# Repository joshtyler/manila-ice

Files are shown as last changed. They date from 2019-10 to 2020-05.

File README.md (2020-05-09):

# manila iCE

manila iCE is a credit card sized Lattice iCE40 development board.

Quick links:
* [Schematic](https://github.com/joshtyler/manila-ice/releases/download/hardware_v1.0/manila_ice-schematic.pdf)
* [Gerbers](https://github.com/joshtyler/manila-ice/releases/download/hardware_v1.0/manila_ice-fab.zip)

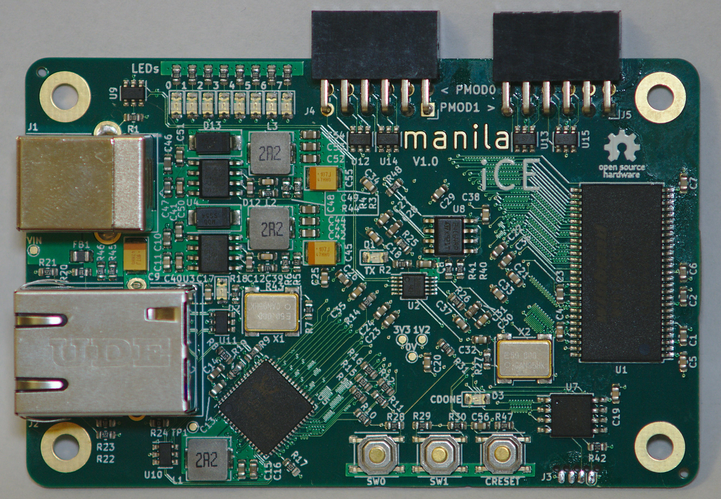
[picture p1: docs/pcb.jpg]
PCB


Features:
* Credit card sized (85x54mm)
* iCE40 HX4K FPGA (usable as an 8k device in yosys)
* Gigabit Ethernet
* 128Mbit SDRAM
* Two dual row PMODs
* 128Mbit QSPI flash
* USB UART (2Mbaud speed)
* 50MHz oscillator
* 64kbit I2C EEPROM
* 8 LEDs
* 2 push buttons
* 3A 3V3 and 1V2 power supplies

## Bootloader

The board has a bootloader which supports loading of FPGA bitstreams over UART. Four slots for bitstreams are supported. The first is reserved for the bootloader itself, and the other three can hold user images.

The FPGA is configured with the bootloader on powerup, and then automatically boots into the first bitstream after a timeout. Alternate bitstreams can be selected using the buttons, or by UART command.

## Example applications

The following applications are provided to demonstrate functionality of the PCB:
* UART loopback
* SDRAM controller
* Gigabit ethernet loopback

## Programming Application

To support uploading user applications, a Linux software utility is provided to update any of the bitstream slots.

To install the software checkout this repository, and run the following commands:
1. `cd sw/scripts`
1. `make`
1. `make install`

You will now have an executable called `manila` in your path.

To program the FPGA:
1. Plug in the board with USB
1. Press either of the switches to pause the boot process (optional if you're quick!)
1. `manila prog [path to bitstream]`

To discover the optional arguments run `manila prog` without any arguments.

## SPI Flash

The SPI flash memory is laid out as follows:

Flash Layout

The bootloader partition is protected to prevent accidental erasure.

## Bootloader Upgrades

In order to allow for firmware upgrades the protection is volatile. When the firmware is configured with the bootloader, before UART commands are accpeted it sends commands to the SPI flash to write protect the bootloader region, and then locks out that configuration until the SPI flash is power cycled.

TODO: document process for upgrading bootloader

## PCB Errata
* v1.0 - No known issues affecting functionality
	* LEDs in ethernet phy do not light due to symbol error
	* Silkscreen box around phtograph on back does not fully enclose image after fab
	* Caption for photograph on back is difficult to read

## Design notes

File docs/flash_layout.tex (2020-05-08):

\documentclass{standalone}

\usepackage{bytefield}

% Memory layout taken from https://www.martin-demling.de/2011/06/memory-maps-in-latex-using-the-bytefield-package/
\newcommand{\memsection}[4]{
	\bytefieldsetup{bitheight=#3\baselineskip}    % define the height of the memsection
	\bitbox[]{10}{
		\texttt{#1}     % print end address
		\\ \vspace{#3\baselineskip} \vspace{-2\baselineskip} \vspace{-#3pt} % do some spacing
		\texttt{#2} % print start address
	}
	\bitbox{16}{#4} % print box with caption
}

\begin{document}
\begin{bytefield}{24}
	\memsection{ffffff}{100000}{10}{Free}\\
	\begin{rightwordgroup}{Slot 3}
		\memsection{0fffff}{0e0fbc}{3}{Application specific data}\\
		\memsection{0e0fbb}{0c0000}{4}{Image}
	\end{rightwordgroup}\\
	\begin{rightwordgroup}{Slot 2}
		\memsection{0bffff}{0a0fbc}{3}{Application specific data}\\
		\memsection{0a0fbb}{080000}{4}{Image}
	\end{rightwordgroup}\\
	\begin{rightwordgroup}{Slot 1}
		\memsection{07ffff}{060fbc}{3}{Application specific data}\\
		\memsection{060fbb}{040000}{4}{Image}
	\end{rightwordgroup}\\
	\begin{rightwordgroup}{Slot 0 (Bootloader) \\ \textbf{Write protected}}
		\memsection{03ffff}{02105c}{3}{Reserved}\\
		\memsection{02105b}{0000a0}{4}{Bootloader image}\\
		\memsection{00009f}{000000}{3}{Multiboot header}
	\end{rightwordgroup}\\
\end{bytefield}
\end{document}

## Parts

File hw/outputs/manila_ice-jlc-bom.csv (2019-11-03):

Comment | Designator | Footprint | LCSC Part #
100n Unpolarized capacitor | C1,C2,C3,C4,C5,C6,C7,C8,C15,C13,C17,C27,C30,C21,C22,C24,C25,C20,C26,C19,C33,C32,C29,C23,C18,C34,C35,C36,C37,C56,C38,C41,C11,C51,C47 | C_0603_1608Metric | C14663
100u Polarized capacitor | C9,C45,C55 | CP_EIA-3528-21_Kemet-B | C16133
22u Unpolarized capacitor | C10,C43,C42,C44,C46,C53,C52,C54 | C_0603_1608Metric | C59461
10p Unpolarized capacitor | C12,C48 | C_0603_1608Metric | C1634
4u7 Unpolarized capacitor | C16,C14,C28,C31 | C_0603_1608Metric | C19666
1n Unpolarized capacitor | C39,C49 | C_0603_1608Metric | C1588
10n Unpolarized capacitor | C40,C50 | C_0603_1608Metric | C57112
LED Light emitting diode | D1,D2,D3,D4,D5,D6,D7,D8,D9,D10,D11 | D_0805_2012Metric_Castellated | C84256
SS54 Diode | D12,D13 | D_SMA | C22452
GZ2012D101TF Ferrite bead | FB1 | L_0805_2012Metric | C1015
2u2 Inductor | L1,L2,L3 | L_Sunlord_MWSA0518_5.4x5.2mm | C408345
1k Resistor | R1,R2,R31,R32,R33,R34,R35,R36,R37,R38,R39 | R_0603_1608Metric | C21190
7k5 Resistor | R3 | R_0603_1608Metric | C23234
1k2 Resistor | R5 | R_0603_1608Metric | C22765
2k4 Resistor | R6,R4,R19 | R_0603_1608Metric | C22940
91 Resistor | R8 | R_0603_1608Metric | C25199
510 Resistor | R20,R23,R18 | R_0603_1608Metric | C23193
4k7 Resistor | R21,R22,R17,R15,R13,R12,R11,R16,R10,R14 | R_0603_1608Metric | C23162
0R Resistor | R24 | R_0603_1608Metric | C21189
100 Resistor | R25,R26,R47 | R_0603_1608Metric | C22775
10k Resistor | R41,R40,R48,R7,R9,R30,R29,R28,R27,R42 | R_0603_1608Metric | C25804
43k Resistor | R43,R44 | R_0603_1608Metric | C23172
360k Resistor | R45 | R_0603_1608Metric | C23146
180k Resistor | R46 | R_0603_1608Metric | C22827
SW_SPST Single Pole Single Throw (SPST) switch | SW3,SW2,SW1 | SW_Push_1P1T_NO_5.1x5.1mm | C318888
W9812G6KH-6 128Mb Synchronous DRAM, 2 Mb x 16 b x 4 Banks, 166 MHz, TSOP-II-54 | U1 | TSOP-II-54_22.2x10.16mm_P0.8mm | C62379
CH340E USB serial converter, UART, MSOP-10 | U2 | MSOP-10_3x3mm_P0.5mm | C99652
TPS54331D 3A, Step Down DC-DC Converter with Eco-mode, 3.5-28V Input Voltage, SO-8 | U3,U4 | SOIC-8_3.9x4.9mm_P1.27mm | C9865
RTL8211EG-VB-CG 10/100/1000Mbps Ethernet Transceiver with RGMII/GMII/MII/RMII Interface | U5 | QFN-64-1EP_9x9mm_P0.5mm_EP3.8x3.8mm_ThermalVias | C69264
W25Q128JVS 128Mb Serial Flash Memory, Standard/Dual/Quad SPI, SOIC-8 | U7 | SOIC-8_5.23x5.23mm_P1.27mm | C97521
M24C01-RMN 1Kb (128x8) I2C Serial EEPROM, 1.8-5.5V, SOIC-8 | U8 | SOIC-8_3.9x4.9mm_P1.27mm | C79988
SRV05-4 ESD Protection Diodes with Low Clamping Voltage, SOT-23-6 | U9,U10,U11,U12,U14,U13,U15 | SOT-23-6 | C85364
SG-7050CAN CMOS Clock Oscillator 1 to 75 MHz | X1,X2 | Oscillator_SMD_SeikoEpson_SG8002CA-4Pin_7.0x5.0mm | C70528

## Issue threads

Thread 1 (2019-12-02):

Very nice board.

janrinze, 2019-12-02:
I like this board.
SDRAM + 2x PMOD is really nice.
If you will be having any spares then I am willing to buy one from you.

Great work!
Jan Rinze.

joshtyler, 2019-12-03:
Hi Jan,

Thank you, I'm glad you like it. I'm impressed that you found the board given that I haven't got around to uploading any documentation yet!

I've had a few boards manufactured and am now testing them.
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

I wanted to try out whether it was possible to get any reasonable gigabit ethernet performance with an iCE40 FPGA, so I put together this credit card sized dev board. It has a GE Phy, SDRAM, 2 PMODs, a reasonable size QSPI flash, and a USB UART. There are also a couple of switches, 8 debug LEDs, and an EEPROM to store things like serial numbers and MAC addresses.

So far I've tested that the power rails come up, that FPGA can configure itself and blink the LEDs, the USB UART, and that the PHY is able to negotiate to 1000BASE-T.

I'm just writing a small bootloader to take in a configuration image over the UART interface and save it into flash, then it should be usable as a standalone unit.

Once I've gotten this done, and tested the other interfaces, I'll let you know, as I should have a few spare boards. Progress might be a bit slow though, as I'm just working on this in a bit of my spare time!

janrinze, 2020-02-19:
Hi, it's been a while.
How is it going with the board?

joshtyler, 2020-02-29:
Hi Jan,

I've got the serial bootloader working, so I can now upload code to the board without a separate programming cable - I've just got to test the various peripherals and interfaces now.

joshtyler, 2020-10-25:
Hi Jan,

Sorry for not getting back to you, this Issue completely slipped my mind! I do have a few spare boards. Happy to sell one to you.

Give me an email at josh.tyler@btinternet.com if you are still interested and we can discuss :smile:

Josh

Closed 2020-10-25.

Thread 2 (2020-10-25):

BOM cost?

taktoa, 2020-10-25:
I'm designing a similar board (HX4K + gigabit ethernet PHY) and I'm curious what your BOM cost ended up being? What about total cost per board from JLC (including board, stencil, assembly, etc.)? If my design ends up being more expensive, I'll know I did something wrong :-)

joshtyler, 2020-10-25:
Hi @taktoa,

You can play around with pricing yourself if you like. You just need the following files:
https://github.com/joshtyler/manila-ice/blob/master/hw/outputs/fab.zip
https://github.com/joshtyler/manila-ice/blob/master/hw/outputs/manila_ice-jlc-bom.csv
https://github.com/joshtyler/manila-ice/blob/master/hw/outputs/manila_ice-jlc-cpl-top.csv

Just drag fab.zip onto the JLC quote form, select SMT assembly, then upload the CSV files when prompted. I've just done a quick check and the assembled board currently costs $100.12 in quantity 5 (without shipping, but with optional ENIG finish), I ordered slightly more PCBs and so paid a slightly lower unit cost.

JLC assemble everything on this board except for the FPGA (which is on the back of the PCB), and the connectors. I think I paid about $5 per FPGA from RS (a UK based distributor). The other connectors were from LCSC. The RJ45 I think was about $2 (it is a bit more expensive than others on the site because it has gigabit magnetics integrated). The PMOD connectors and USB connectors I think were tens of cents each.

You don't need to pay for a stencil explicitly (JLC bake it into the assembly cost) but if you want one shipped to you, then it costs $7.

Btw, if you're thinking of doing gigabit networking on the iCE40 FPGAs, bear in mind that the fabric is fairly slow, getting the ethernet interface working at 125 MHz can be a challenge. I can get a loopback test to meet timing at 125MHz no problem, but as I add more to the design, it becomes harder to meet timing. For example with a picorv32 CPU in there, the ethernet doesn't quite meet timing anymore (even though the ethernet clock domain just has a FIFO, and some discrete logic to drive the MII interface). I'm currently looking at implementing TCP in the FPGA logic, and I'm fairly confident that I will be able to get this to meet timing :smile:

taktoa, 2020-10-25:
Thanks! Gigabit is fortunately not important for my application, but I figured I'd rather have it and not use it than not have it and want it. My application is actually a microphone array for playing around with ultrasound sonar in air (e.g.: to make a depth camera), and the total data rate there is 72 Mb/s, but if I want to get into higher frequency ultrasound the gigabit would come in handy. My board will also have a microcontroller (leaning towards a RISC-V core, funnily enough) so the FPGA is really just there to route data and do serial-to-parallel / parallel-to-serial conversion; setting up protocols will be done by the microcontroller.

Closed 2020-10-25.

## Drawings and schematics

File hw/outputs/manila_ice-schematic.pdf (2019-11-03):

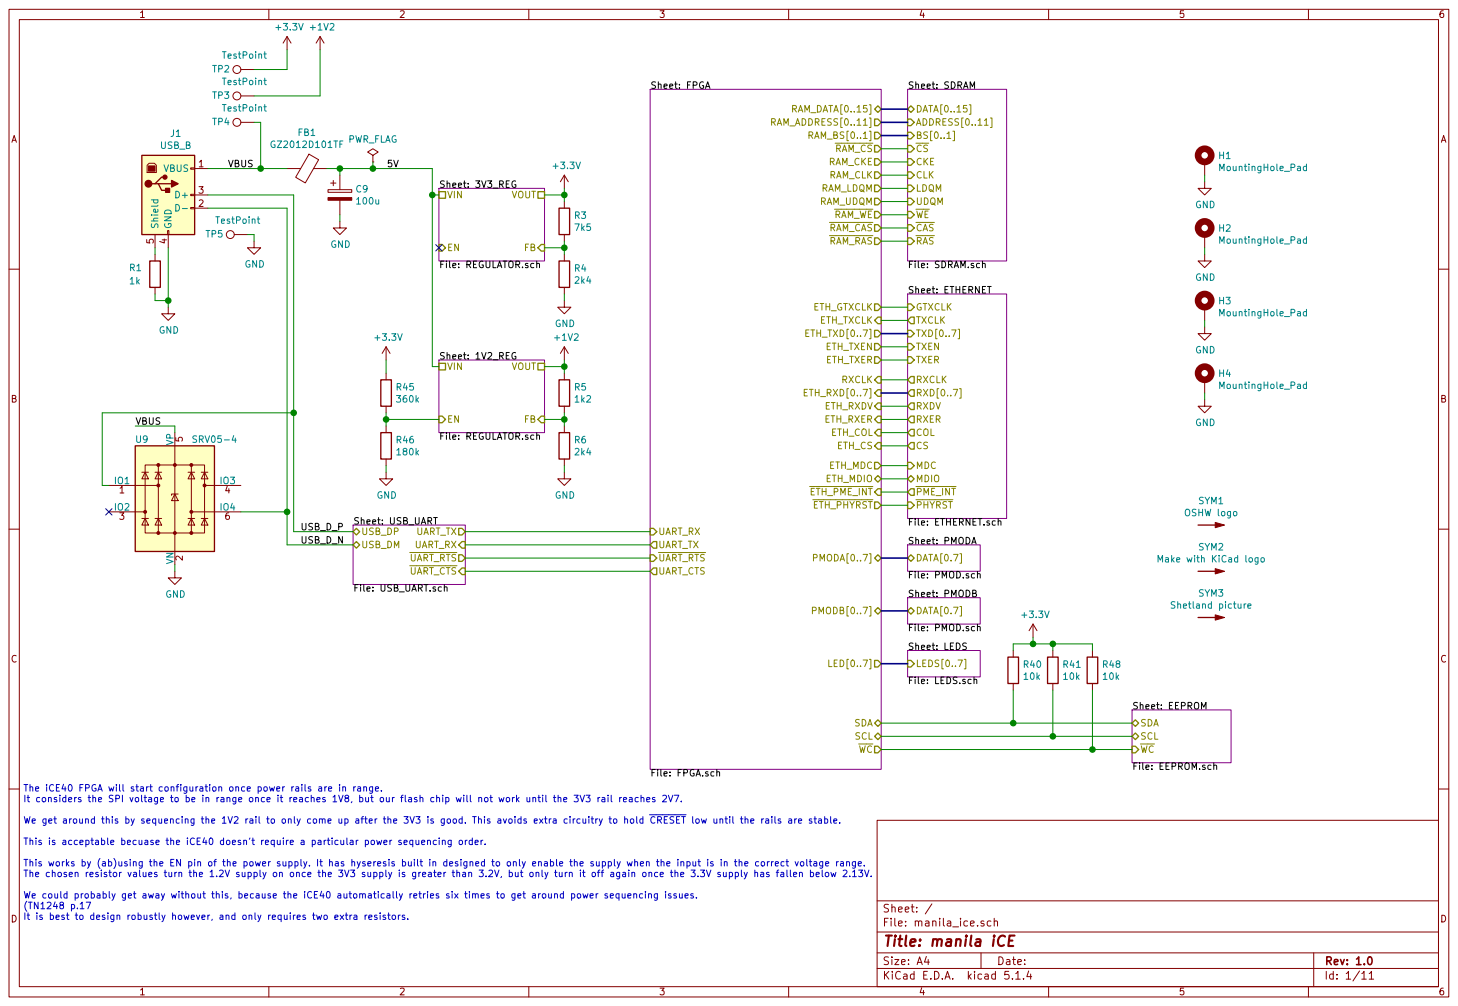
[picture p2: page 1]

DATA[0..15]
File: SDRAM.sch ADDRESS[0..11]
BS[0..1] CSCKE CLK

LDQM
UDQM WE CAS RAS
File: ETHERNET.sch GTXCLK
TXCLK
TXD[0..7] TXEN

SYM1 OSHW logo SYM2 Make with KiCad logo SYM3 Shetland picture GND

TXER
RXCLK RXD[0..7] RXDV RXER

COL CSMDC MDIO
LEDS[0..7] Sheet: PMODA
File: PMOD.sch DATA[0.7]

File: PMOD.sch DATA[0.7] GND

File: manila_ice.sch Sheet: / Sheet: USB_UART
File: USB_UART.sch USB_DP USB_DM

Sheet: EEPROM
File: EEPROM.sch SDA
SCL WC

The iCE40 FPGA will start configuration once power rails are in range.
It considers the SPI voltage to be in range once it reaches 1V8, but our flash chip will not work until the 3V3 rail reaches 2V7.

We get around this by sequencing the 1V2 rail to only come up after the 3V3 is good. This avoids extra circuitry to hold CRESET low until the rails are stable.

This is acceptable becuase the iCE40 doesn't require a particular power sequencing order.

This works by (ab)using the EN pin of the power supply. It has hyseresis built in designed to only enable the supply when the input is in the correct voltage range.
The chosen resistor values turn the 1.2V supply on once the 3V3 supply is greater than 3.2V, but only turn it off again once the 3.3V supply has fallen below 2.13V.

We could probably get away without this, because the iCE40 automatically retries six times to get around power sequencing issues.
It is best to design robustly however, and only requires two extra resistors.

Id: 1/11 Title: manila iCE

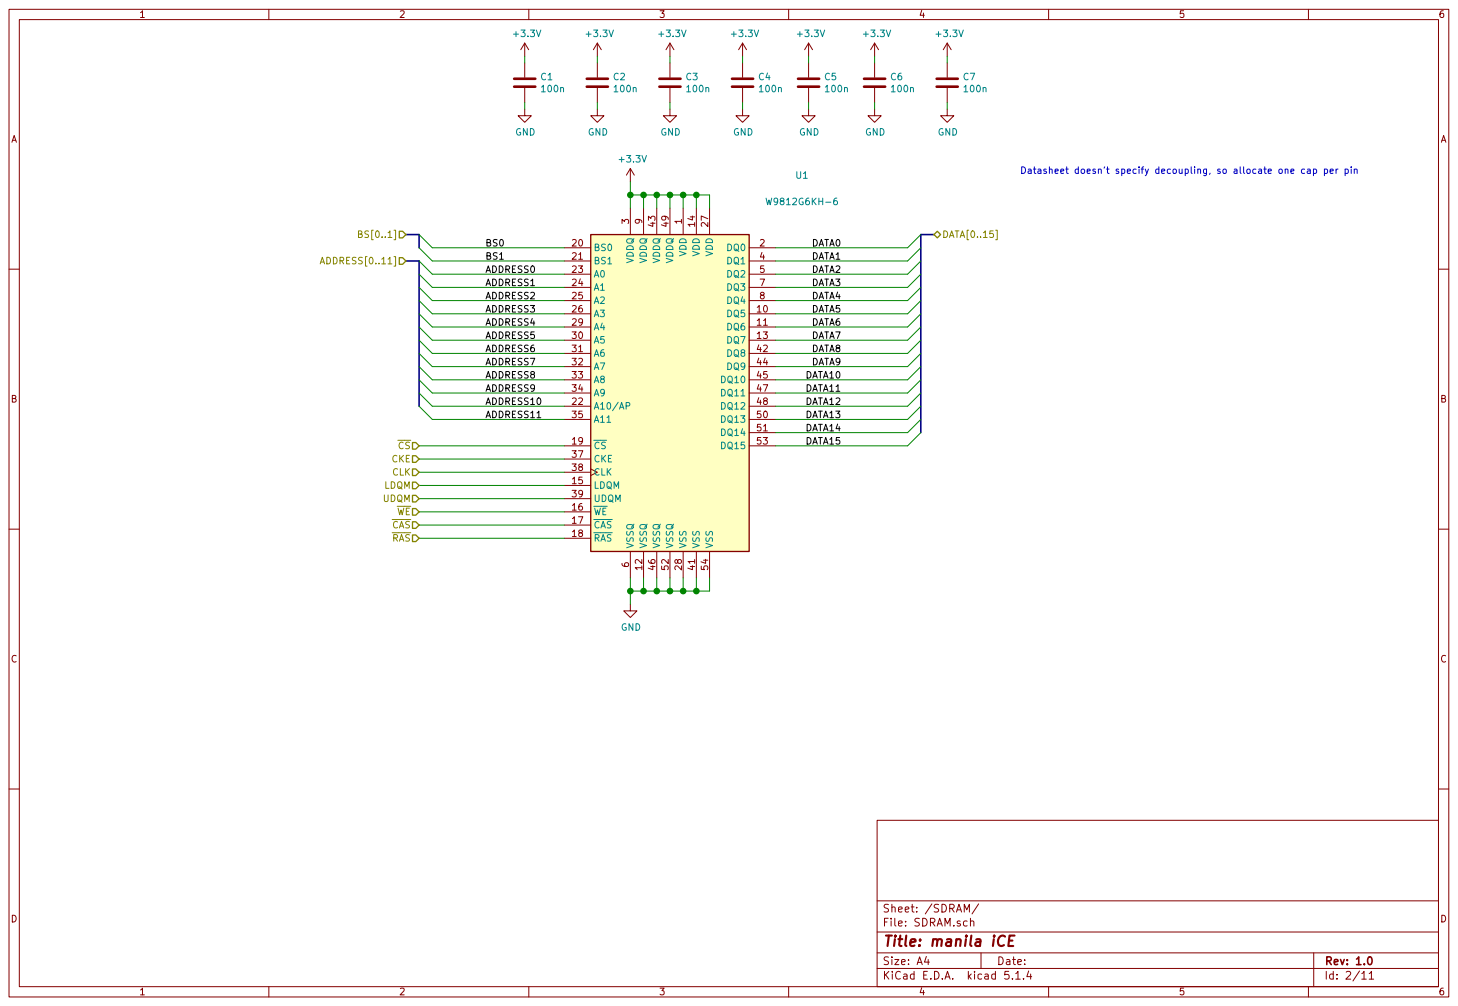
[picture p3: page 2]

100n ADDRESS[0..11]RAS CAS WE UDQM

3 A5 30 A6 31 A7 32 A8 33 A9 34 A11 35 CKE 37 CLK 38 UDQM 39 DQ1 4 VSS 41 DQ8 42 VDDQ 43 DQ9 44 DQ10 45 VSSQ 46 DQ11 47 DQ12 48 VDDQ 49 DQ2 5 DQ13 50 DQ14 51 VSSQ 52 DQ15 53 VSS 54 VSSQ

File: SDRAM.sch Sheet: /SDRAM/
Id: 2/11 Title: manila iCE

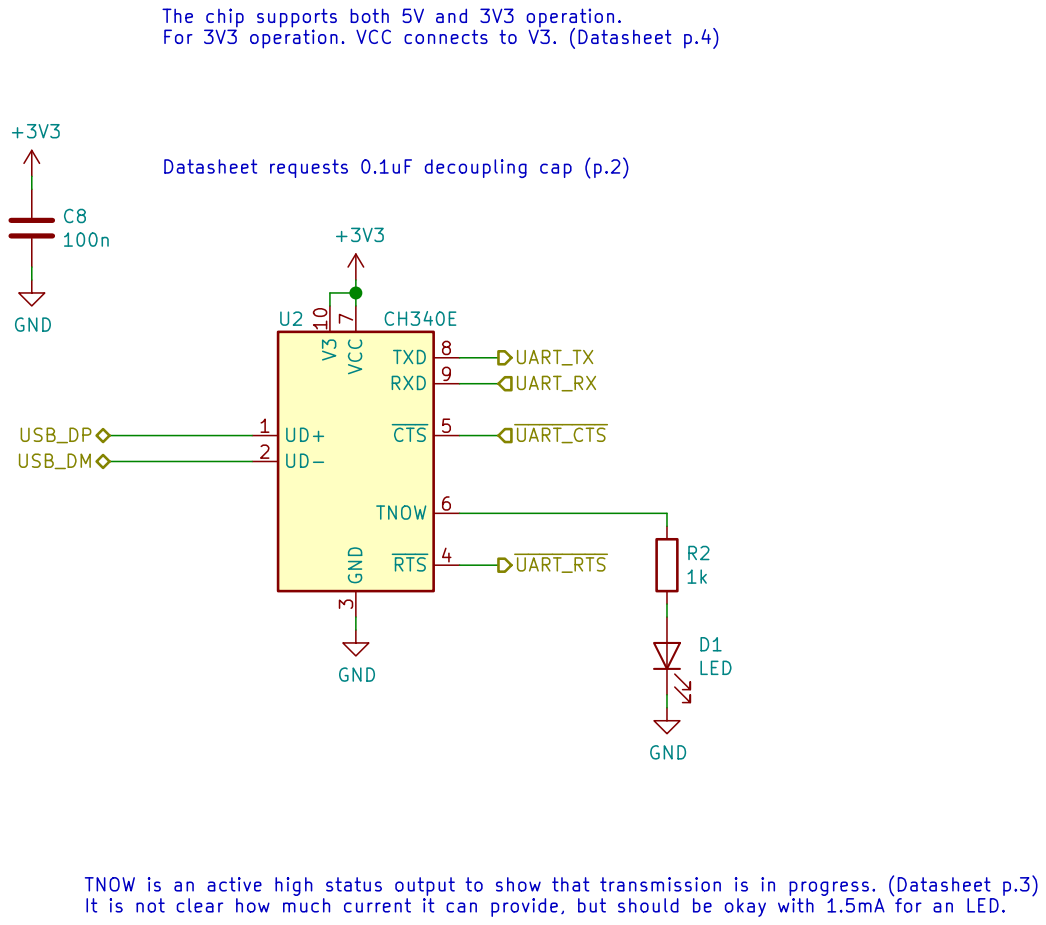
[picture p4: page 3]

The chip supports both 5V and 3V3 operation.
For 3V3 operation. VCC connects to V3. (Datasheet p.4)
100n +3V3 GND

3 RTS 4 CTS 5 TNOW 6 VCC

TNOW is an active high status output to show that transmission is in progress. (Datasheet p.3)
It is not clear how much current it can provide, but should be okay with 1.5mA for an LED.

File: USB_UART.sch
Id: 3/11 Title: manila iCE

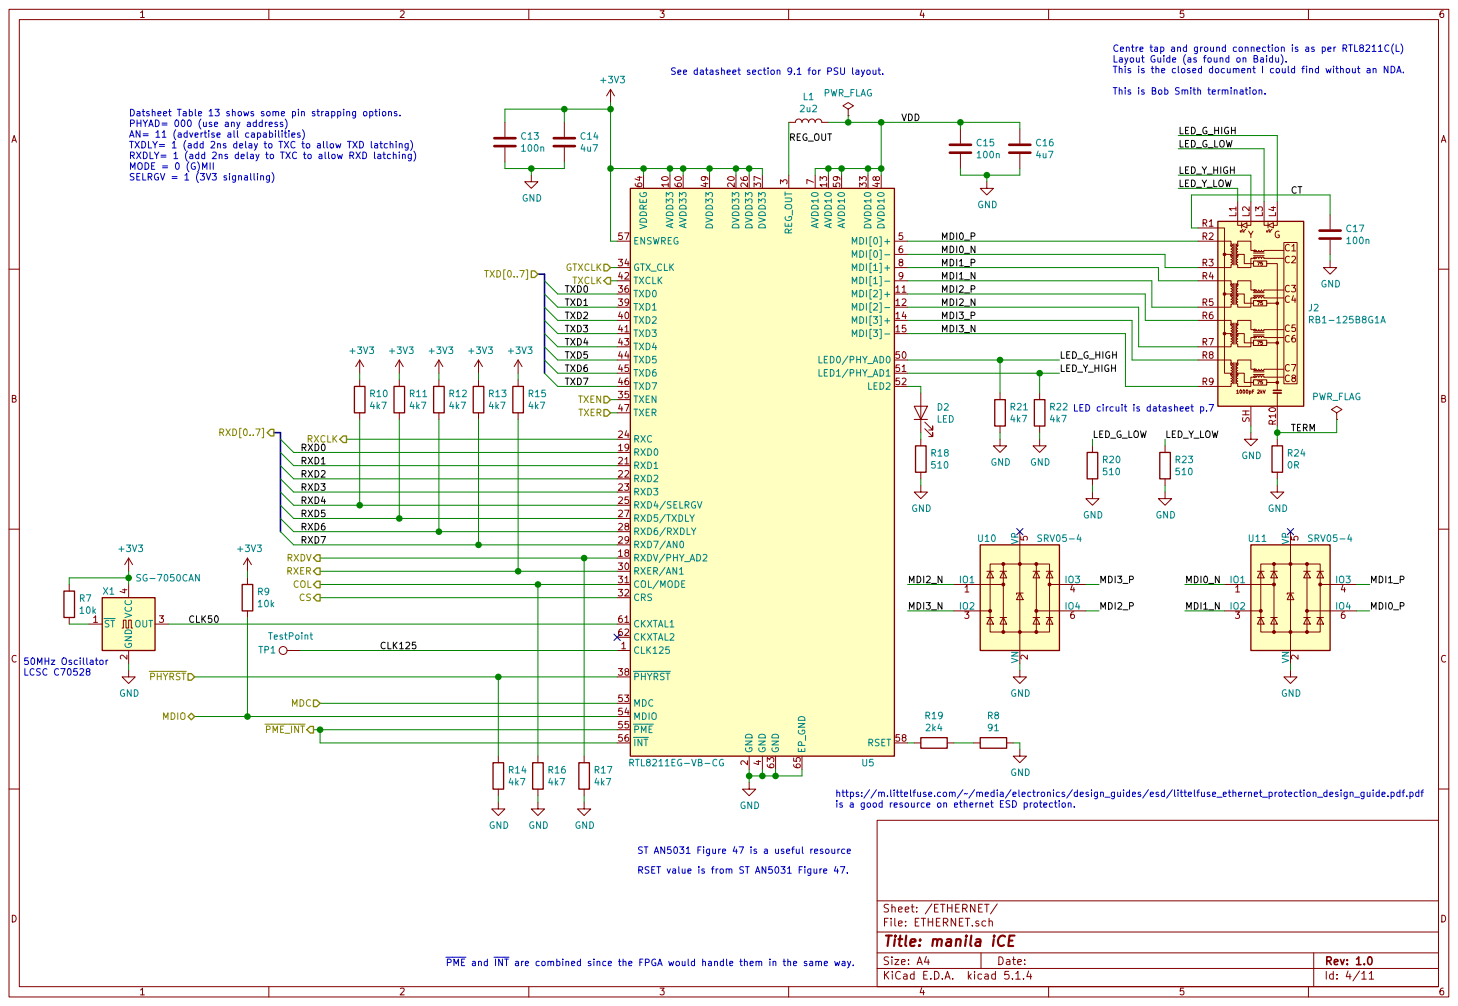
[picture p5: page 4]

Centre tap and ground connection is as per RTL8211C(L)
Layout Guide (as found on Baidu). This is the closed document I could find without an NDA. This is Bob Smith termination.

See datasheet section 9.1 for PSU layout.

Datsheet Table 13 shows some pin strapping options.
PHYAD= 000 (use any address)
AN= 11 (advertise all capabilities)
TXDLY= 1 (add 2ns delay to TXC to allow TXD latching)
RXDLY= 1 (add 2ns delay to TXC to allow RXD latching)
MODE = 0 (G)MII
SELRGV = 1 (3V3 signalling)

7 MDI[1]+ 8 MDI[1]- 9 RTL8211EG-VB-CG U5 +3V3 GND GND GND

2 DVDD33 20 RXD1 21 RXD2 22 RXD3 23 RXC 24 RXD4/SELRGV 25 DVDD33 26 RXD5/TXDLY 27 RXD6/RXDLY 28 RXD7/AN0 29 REG_OUT

3 RXER/AN1 30 COL/MODE 31 CRS 32 DVDD10 33 GTX_CLK 34 TXEN 35 TXD0 36 DVDD33 37 PHYRST 38 TXD1 39 GND

LED circuit is datasheet p.7

COL CS MDC MDIO

https://m.littelfuse.com//media/electronics/design_guides/esd/littelfuse_ethernet_protection_design_guide.pdf.pdf
is a good resource on ethernet ESD protection.

ST AN5031 Figure 47 is a useful resource
RSET value is from ST AN5031 Figure 47.

File: ETHERNET.sch Sheet: /ETHERNET/
Id: 4/11 Title: manila iCE

PME and INT are combined since the FPGA would handle them in the same way.

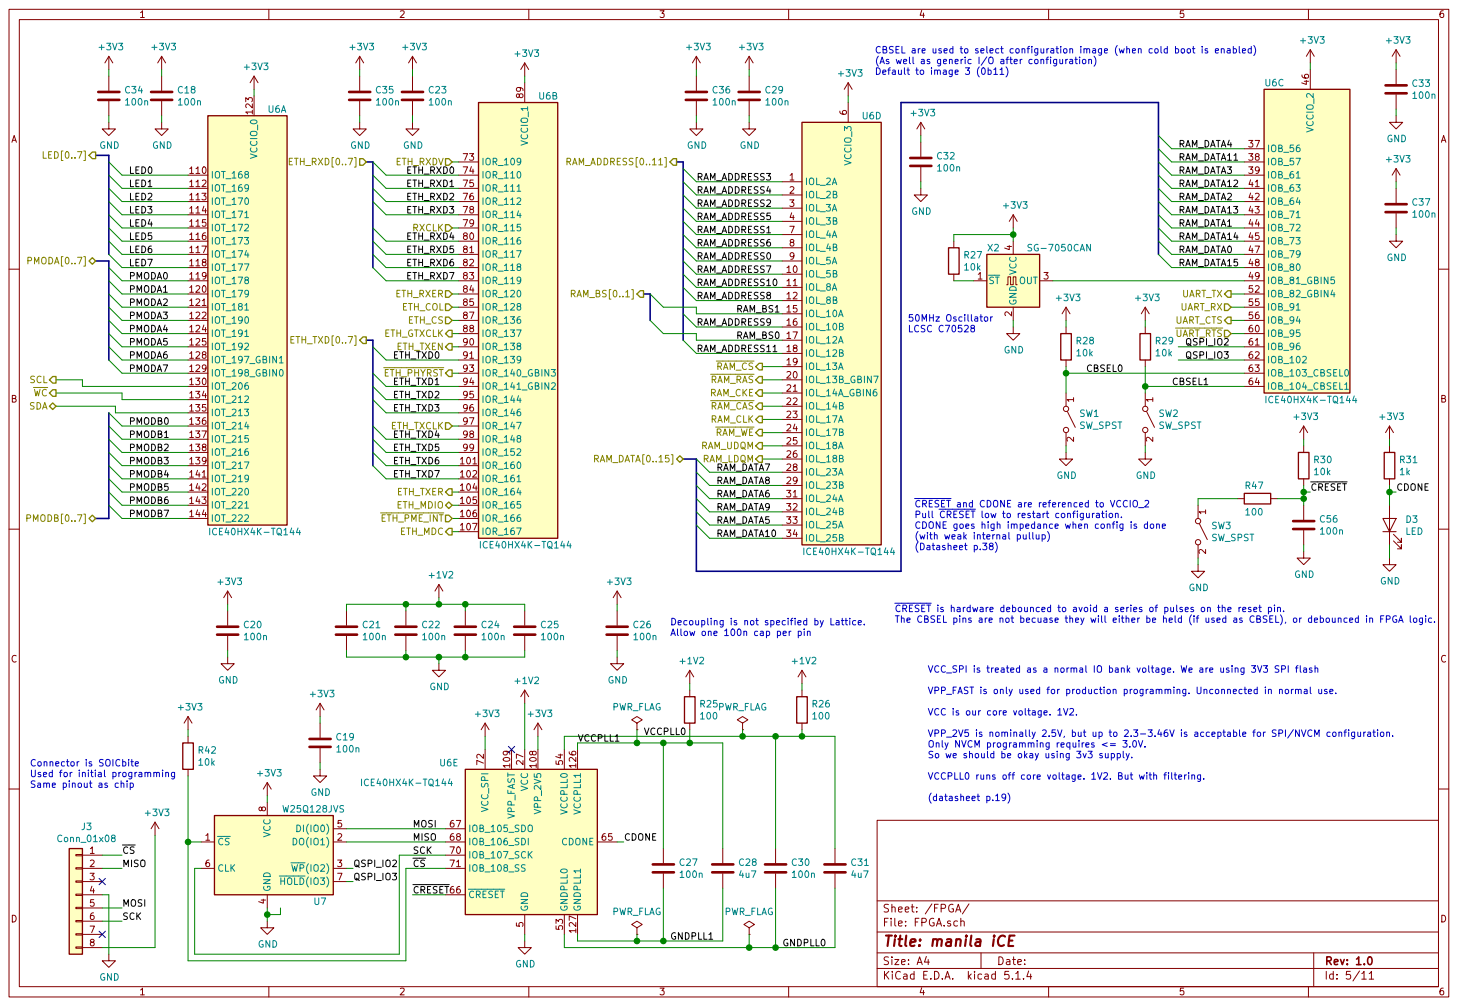
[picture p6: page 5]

CBSEL are used to select configuration image (when cold boot is enabled)
(As well as generic I/O after configuration)
Default to image 3 (0b11) CRESET and CDONE are referenced to VCCIO_2 Pull CRESET low to restart configuration.

CDONE goes high impedance when config is done
(with weak internal pullup)
(Datasheet p.38)

CRESET is hardware debounced to avoid a series of pulses on the reset pin.
The CBSEL pins are not becuase they will either be held (if used as CBSEL), or debounced in FPGA logic.

Decoupling is not specified by Lattice.
Allow one 100n cap per pin

VCC_SPI is treated as a normal IO bank voltage. We are using 3V3 SPI flash

VPP_FAST is only used for production programming. Unconnected in normal use.

VCC is our core voltage. 1V2.

VPP_2V5 is nominally 2.5V, but up to 2.3-3.46V is acceptable for SPI/NVCM configuration.
Only NVCM programming requires <= 3.0V.
So we should be okay using 3v3 supply.

Same pinout as chip

VCCPLL0 runs off core voltage. 1V2. But with filtering.

4 DI(IO0) 5 CLK 6 HOLD(IO3) 7 VCC
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

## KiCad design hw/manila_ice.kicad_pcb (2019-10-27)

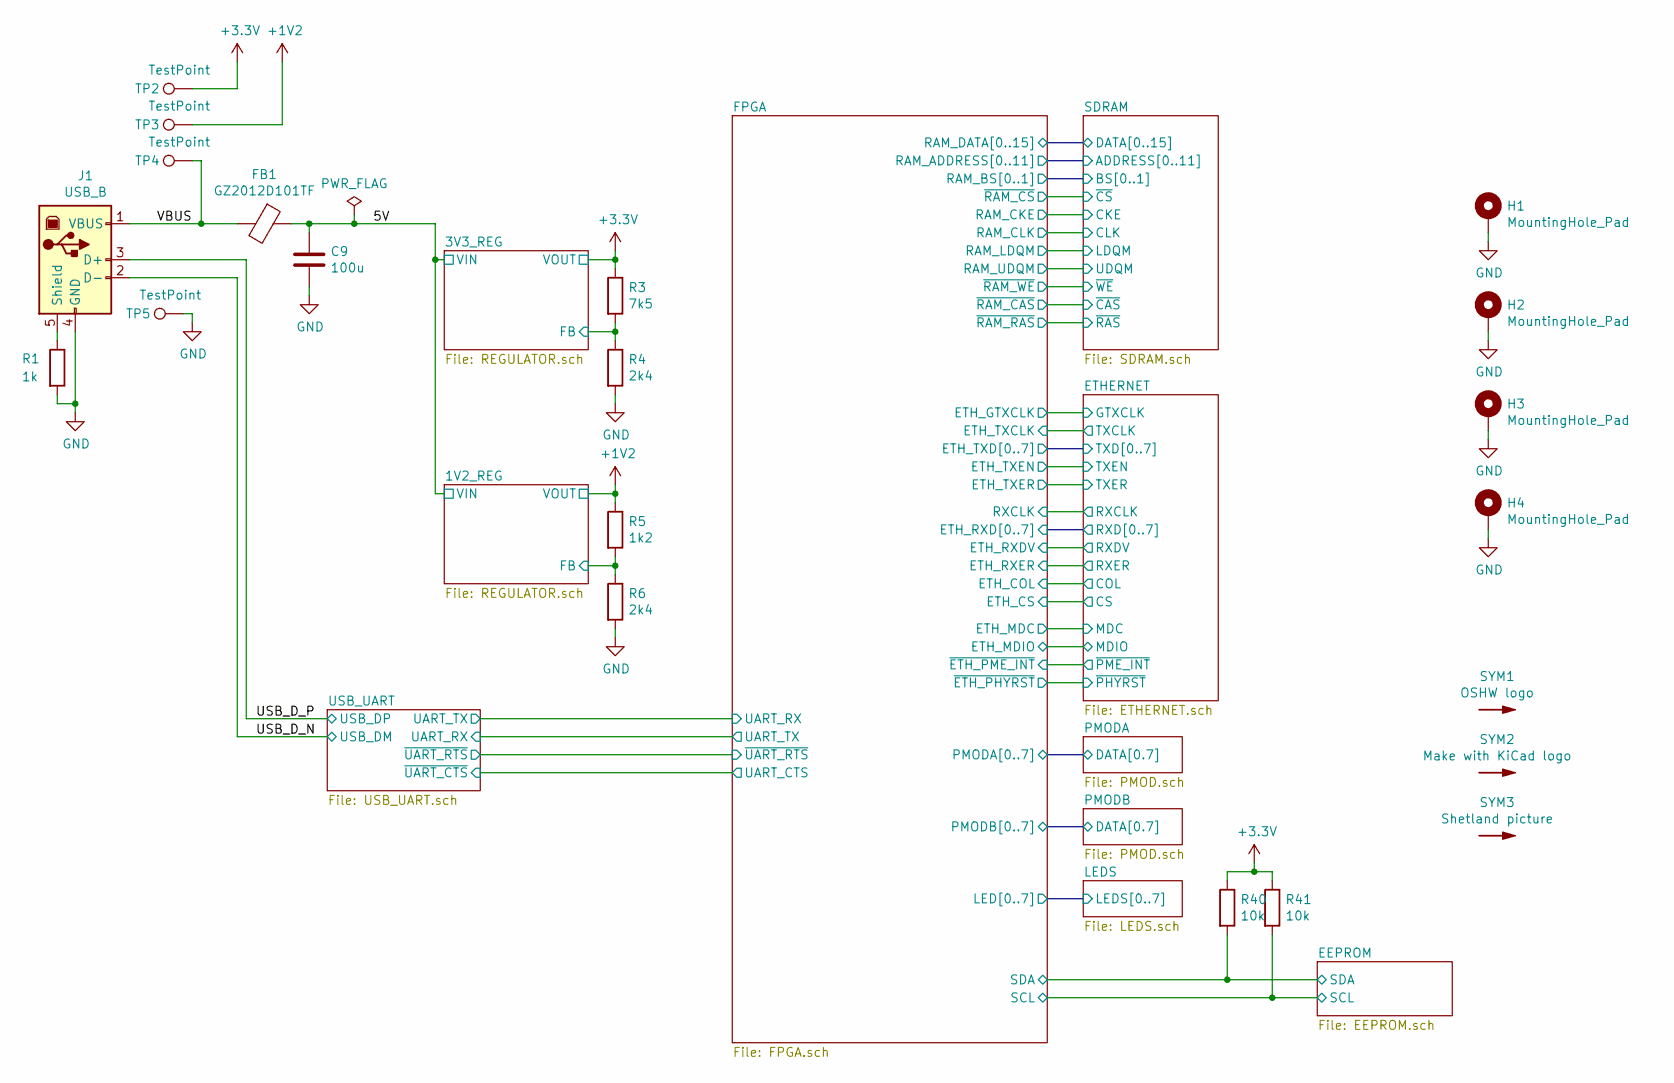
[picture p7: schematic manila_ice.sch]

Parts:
C9: 100u; CP_EIA-3528-21_Kemet-B; LCSC Part C16133
FB1: GZ2012D101TF; L_0805_2012Metric; LCSC Part C1015
H1, H2, H3, H4: MountingHole_Pad; MountingHole_3.2mm_M3_Pad; JLCPCB BOM 0
J1: USB_B; USB_B_OST_USB-B1HSxx_Horizontal; JLCPCB BOM 0
R1: 1k; R_0603_1608Metric; LCSC Part C21190
R3: 7k5; R_0603_1608Metric; LCSC Part C22452
R4, R6: 2k4; R_0603_1608Metric; LCSC Part C22940
R5: 1k2; R_0603_1608Metric; LCSC Part C22765
R40, R41: 10k; R_0603_1608Metric; LCSC Part C25804
SYM1: OSHW logo; OSHW-Logo_5.7x6mm_SilkScreen; JLCPCB BOM 0
SYM2: Make with KiCad logo; KiCad-Logo2_5mm_SilkScreen; JLCPCB BOM 0
SYM3: Shetland picture; Shetland_combined; JLCPCB BOM 0
TP2, TP3, TP4, TP5: TestPoint; TestPoint_Pad_D1.0mm; JLCPCB BOM 0

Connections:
+1V2: R5.1, TP3.1; also elsewhere on the board
/1V2_REG/FB: R5.2, R6.1; also elsewhere on the board
/3V3_REG/FB: R3.2, R4.1; also elsewhere on the board
/5V: C9.1, FB1.1; also elsewhere on the board
/EEPROM/SCL: R41.2; also elsewhere on the board
/EEPROM/SDA: R40.2; also elsewhere on the board
/USB_D_N: J1.2 (D-); also elsewhere on the board
/USB_D_P: J1.3 (D+); also elsewhere on the board
/VBUS: FB1.2, J1.1 (VBUS), TP4.1
GND: C9.2, H1.1, H2.1, H3.1, H4.1, J1.4 (GND), R1.2, R4.2, R6.2, TP5.1; also elsewhere on the board
unnamed: J1.5 (Shield), R1.1

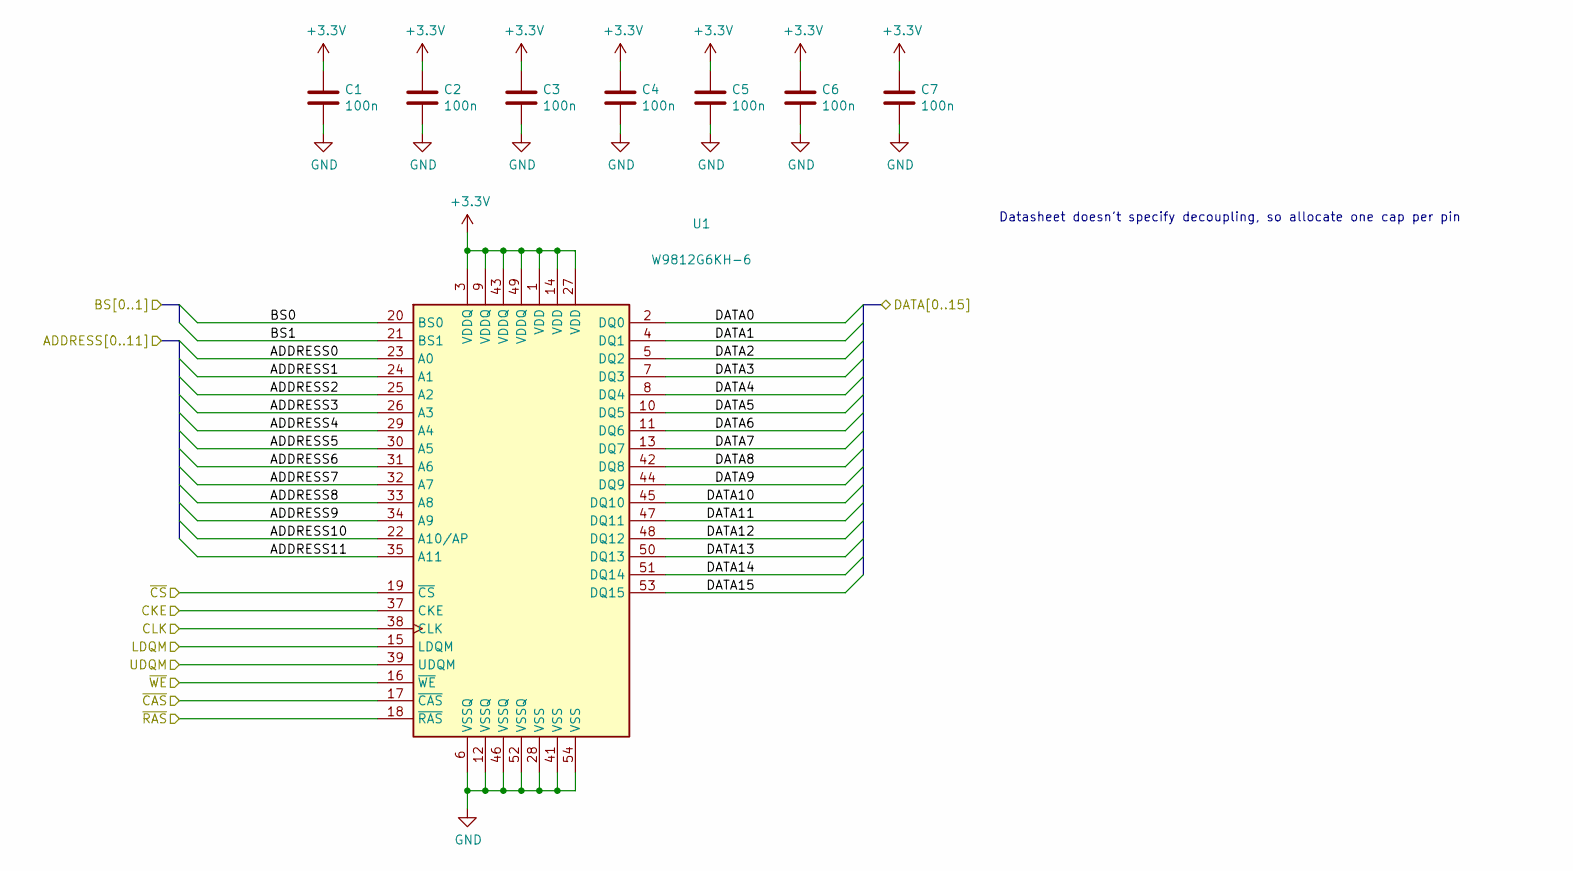
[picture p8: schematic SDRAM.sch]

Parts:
C1, C2, C3, C4, C5, C6, C7: 100n; C_0603_1608Metric; LCSC Part C14663
U1: W9812G6KH-6; TSOP-II-54_22.2x10.16mm_P0.8mm; LCSC Part C62379

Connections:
/FPGA/RAM_UDQM: U1.39 (UDQM); also elsewhere on the board
/FPGA/~RAM_RAS: U1.18 (~RAS); also elsewhere on the board
/FPGA/~RAM_WE: U1.16 (~WE); also elsewhere on the board
/SDRAM/ADDRESS0: U1.23 (A0); also elsewhere on the board
/SDRAM/ADDRESS1: U1.24 (A1); also elsewhere on the board
/SDRAM/ADDRESS2: U1.25 (A2); also elsewhere on the board
/SDRAM/ADDRESS3: U1.26 (A3); also elsewhere on the board
/SDRAM/ADDRESS4: U1.29 (A4); also elsewhere on the board
/SDRAM/ADDRESS5: U1.30 (A5); also elsewhere on the board
/SDRAM/ADDRESS6: U1.31 (A6); also elsewhere on the board
/SDRAM/ADDRESS7: U1.32 (A7); also elsewhere on the board
/SDRAM/ADDRESS8: U1.33 (A8); also elsewhere on the board
/SDRAM/ADDRESS9: U1.34 (A9); also elsewhere on the board
/SDRAM/ADDRESS10: U1.22 (A10/AP); also elsewhere on the board
/SDRAM/ADDRESS11: U1.35 (A11); also elsewhere on the board
/SDRAM/BS0: U1.20 (BS0); also elsewhere on the board
/SDRAM/BS1: U1.21 (BS1); also elsewhere on the board
/SDRAM/CKE: U1.37 (CKE); also elsewhere on the board
/SDRAM/CLK: U1.38 (CLK); also elsewhere on the board
/SDRAM/DATA0: U1.2 (DQ0); also elsewhere on the board
/SDRAM/DATA1: U1.4 (DQ1); also elsewhere on the board
/SDRAM/DATA2: U1.5 (DQ2); also elsewhere on the board
/SDRAM/DATA3: U1.7 (DQ3); also elsewhere on the board
/SDRAM/DATA4: U1.8 (DQ4); also elsewhere on the board
/SDRAM/DATA5: U1.10 (DQ5); also elsewhere on the board
/SDRAM/DATA6: U1.11 (DQ6); also elsewhere on the board
/SDRAM/DATA7: U1.13 (DQ7); also elsewhere on the board
/SDRAM/DATA8: U1.42 (DQ8); also elsewhere on the board
/SDRAM/DATA9: U1.44 (DQ9); also elsewhere on the board
/SDRAM/DATA10: U1.45 (DQ10); also elsewhere on the board
/SDRAM/DATA11: U1.47 (DQ11); also elsewhere on the board
/SDRAM/DATA12: U1.48 (DQ12); also elsewhere on the board
/SDRAM/DATA13: U1.50 (DQ13); also elsewhere on the board
/SDRAM/DATA14: U1.51 (DQ14); also elsewhere on the board
/SDRAM/DATA15: U1.53 (DQ15); also elsewhere on the board
/SDRAM/LDQM: U1.15 (LDQM); also elsewhere on the board
/SDRAM/~CAS: U1.17 (~CAS); also elsewhere on the board
/SDRAM/~CS: U1.19 (~CS); also elsewhere on the board
GND: C1.2, C2.2, C3.2, C4.2, C5.2, C6.2, C7.2, U1.6 (VSSQ), U1.12 (VSSQ), U1.28 (VSS), U1.41 (VSS), U1.46 (VSSQ), U1.52 (VSSQ), U1.54 (VSS); also elsewhere on the board

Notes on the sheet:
Datasheet doesn't specify decoupling, so allocate one cap per pin

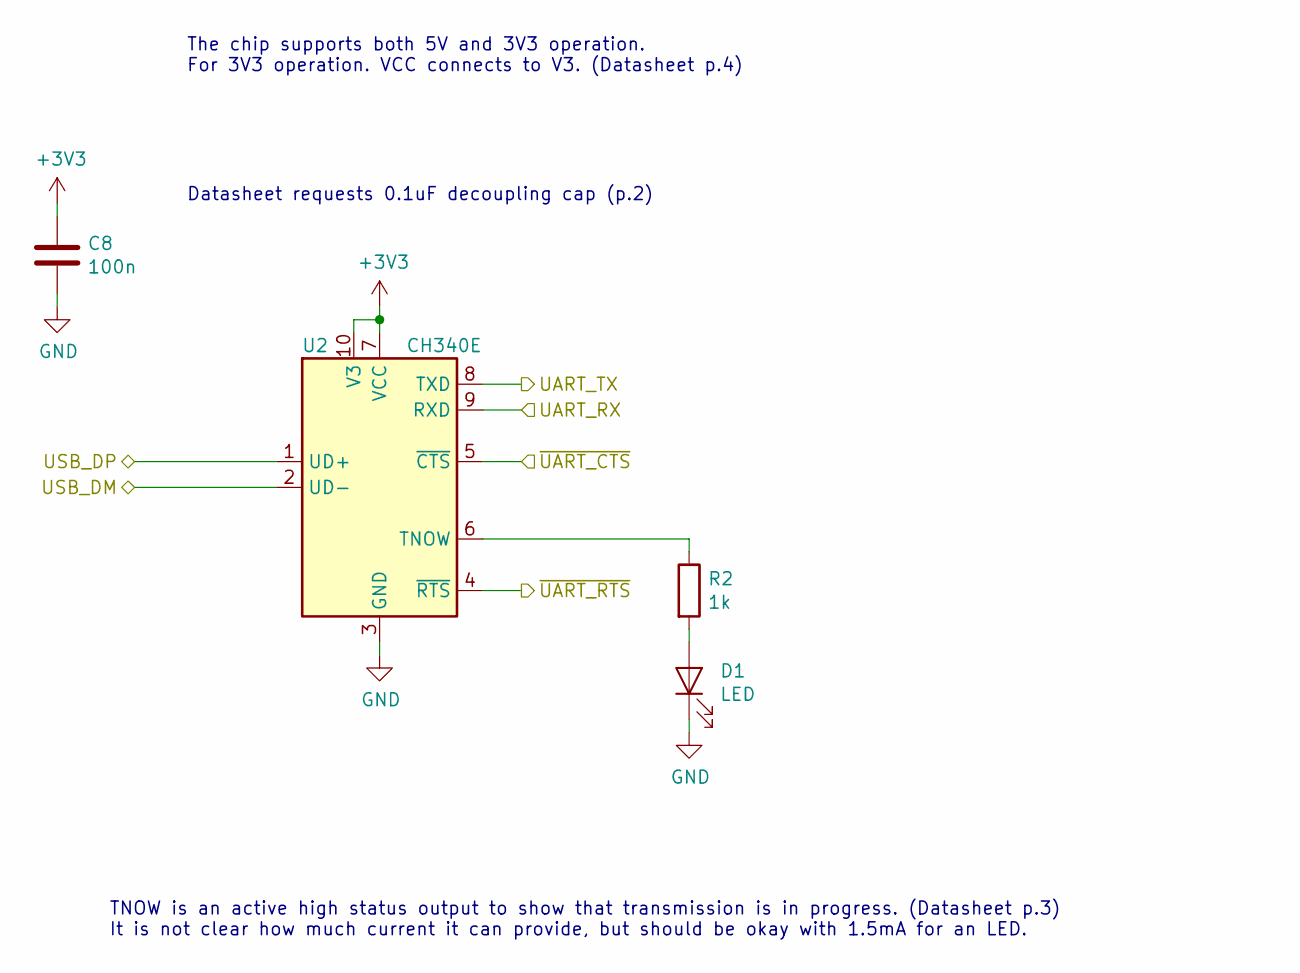
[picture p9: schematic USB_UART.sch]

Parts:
C8: 100n; C_0603_1608Metric; LCSC Part C14663
D1: LED; D_0805_2012Metric_Castellated; LCSC Part C84256
R2: 1k; R_0603_1608Metric; LCSC Part C21190
U2: CH340E; MSOP-10_3x3mm_P0.5mm; JLCPCB Rotation -90

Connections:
/FPGA/UART_CTS: U2.5 (~CTS); also elsewhere on the board
/FPGA/UART_RX: U2.8 (TXD); also elsewhere on the board
/FPGA/~UART_RTS: U2.4 (~RTS); also elsewhere on the board
/USB_D_N: U2.2 (UD-); also elsewhere on the board
/USB_D_P: U2.1 (UD+); also elsewhere on the board
/USB_UART/UART_RX: U2.9 (RXD); also elsewhere on the board
GND: C8.2, D1.1 (K), U2.3 (GND); also elsewhere on the board
unnamed: D1.2 (A), R2.2
unnamed: R2.1, U2.6 (TNOW)

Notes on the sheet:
TNOW is an active high status output to show that transmission is in progress. (Datasheet p.3) It is not clear how much current it can provide, but should be okay with 1.5mA for an LED.
The chip supports both 5V and 3V3 operation. For 3V3 operation. VCC connects to V3. (Datasheet p.4)
Datasheet requests 0.1uF decoupling cap (p.2)

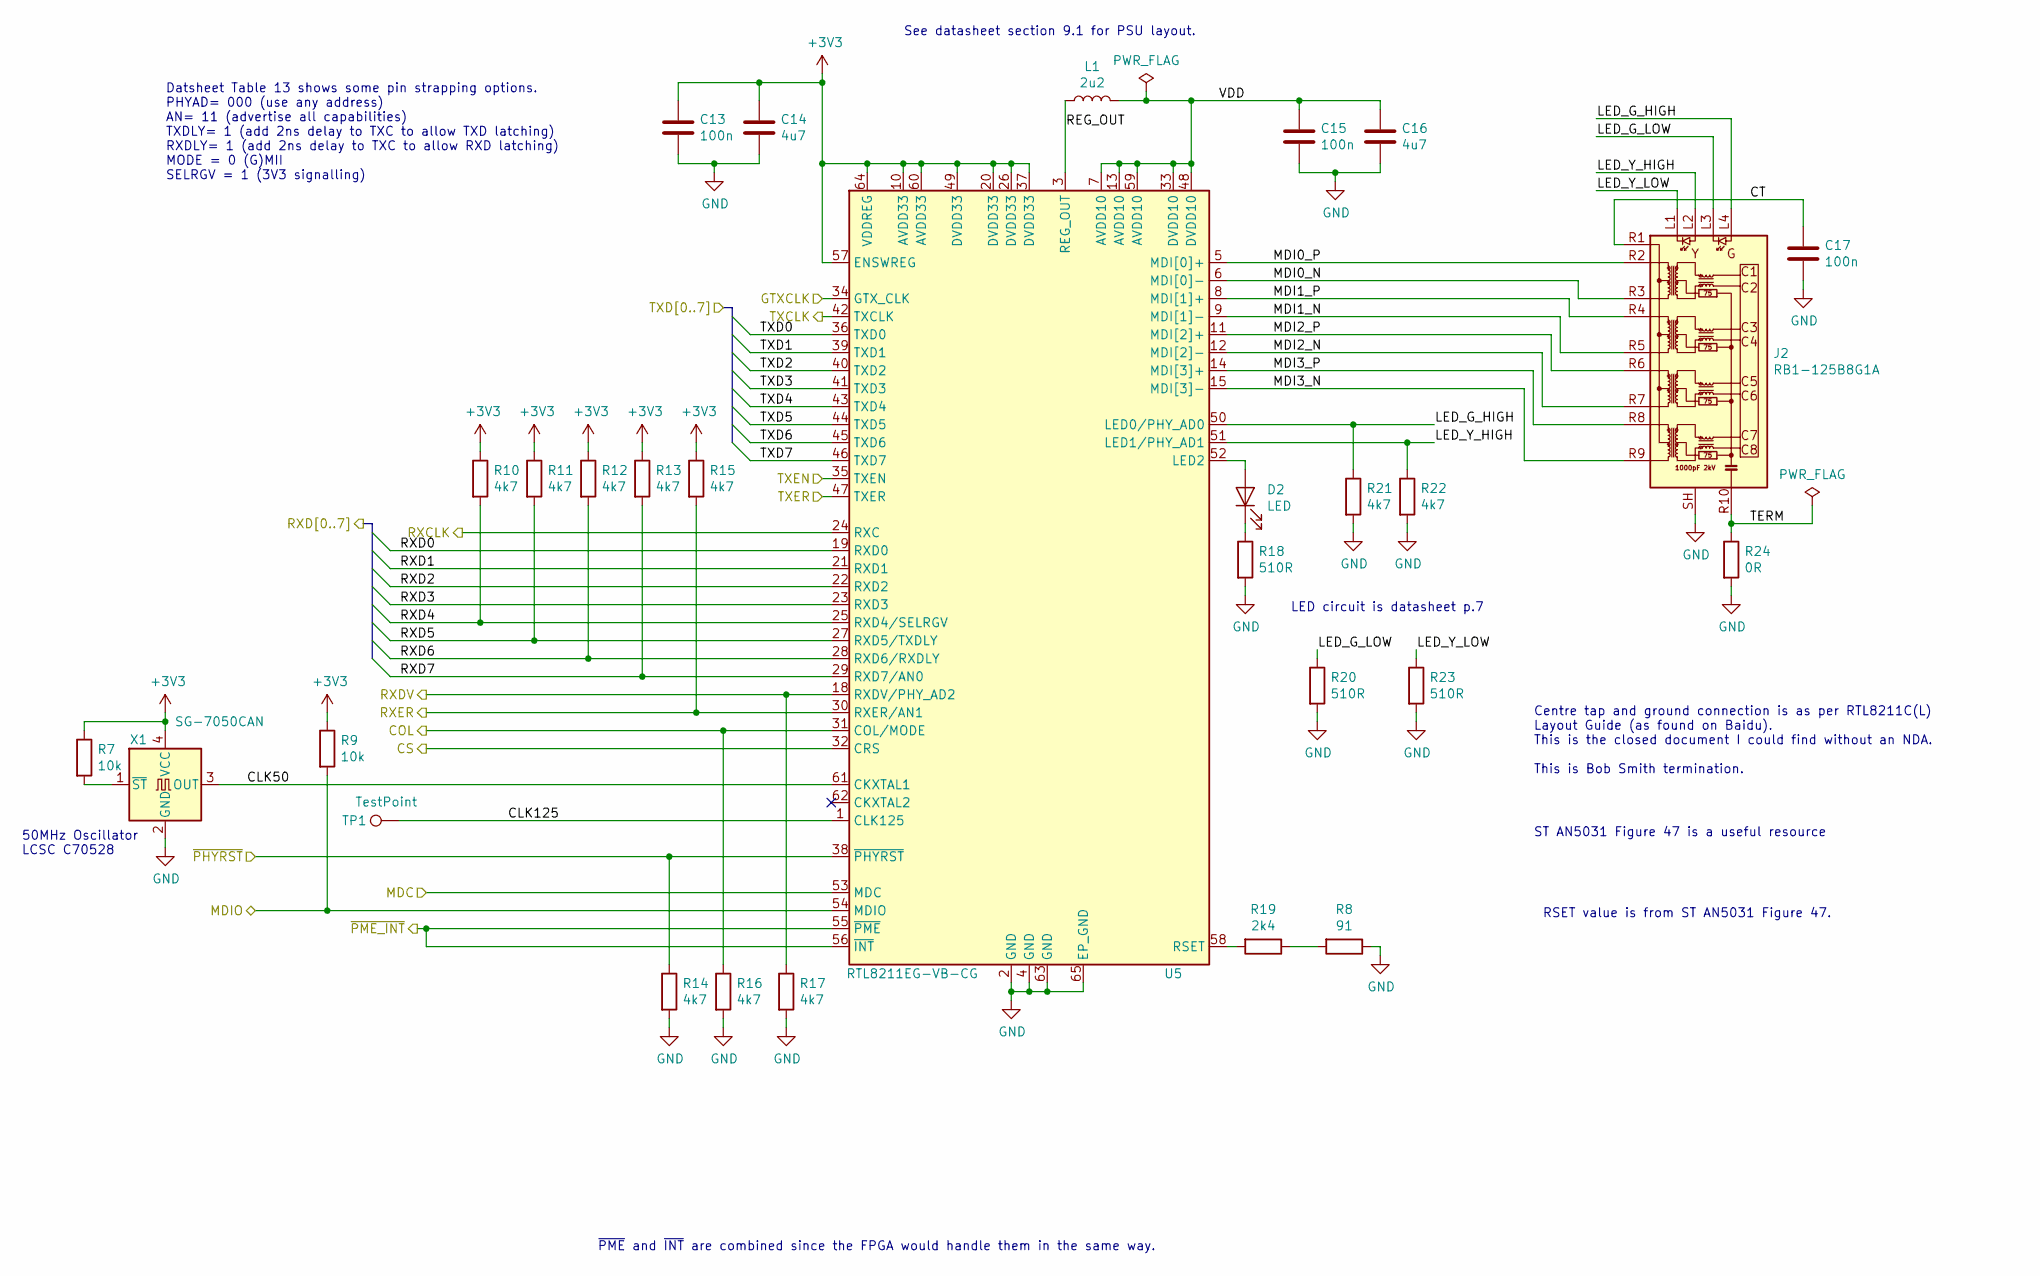
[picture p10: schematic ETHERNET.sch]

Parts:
C13, C15, C17: 100n; C_0603_1608Metric; LCSC Part C14663
C14, C16: 4u7; C_0603_1608Metric; LCSC Part C19666
D2: LED; D_0805_2012Metric_Castellated; LCSC Part C84256
J2: RB1-125B8G1A; RJ45_UDE_RB1-125B8G1A; JLCPCB BOM 0
L1: 2u2; L_Sunlord_MWSA0518; LCSC Part C408345
R7, R9: 10k; R_0603_1608Metric; LCSC Part C25804
R8: 91; R_0603_1608Metric; LCSC Part C25199
R10, R11, R12, R13, R14, R15, R16, R17, R21, R22: 4k7; R_0603_1608Metric; LCSC Part C23162
R18, R20, R23: 510R; R_0603_1608Metric; LCSC Part C23193
R19: 2k4; R_0603_1608Metric; LCSC Part C22940
R24: 0R; R_0603_1608Metric; LCSC Part C21189
TP1: TestPoint; TestPoint_Pad_D1.0mm; JLCPCB BOM 0
U5: RTL8211EG-VB-CG; QFN-64-1EP_9x9mm_P0.5mm_EP3.8x3.8mm_ThermalVias; LCSC Part C69264
X1: SG-7050CAN; Oscillator_SMD_SeikoEpson_SG8002CA-4Pin_7.0x5.0mm; LCSC Part C70528

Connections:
/ETHERNET/CLK50: U5.61 (CKXTAL1), X1.3 (OUT)
/ETHERNET/CLK125: TP1.1, U5.1 (CLK125)
/ETHERNET/COL: R16.1, U5.31 (COL/MODE); also elsewhere on the board
/ETHERNET/CS: U5.32 (CRS); also elsewhere on the board
/ETHERNET/CT: C17.1, J2.R1 (CT)
/ETHERNET/LED_G_HIGH: J2.L4, R21.1, U5.50 (LED0/PHY_AD0)
/ETHERNET/LED_G_LOW: J2.L3, R20.1
/ETHERNET/LED_Y_HIGH: J2.L2, R22.1, U5.51 (LED1/PHY_AD1)
/ETHERNET/LED_Y_LOW: J2.L1, R23.1
/ETHERNET/MDI0_N: J2.R3 (TD1-), U5.6 (MDI[0]-)
/ETHERNET/MDI0_P: J2.R2 (TD1+), U5.5 (MDI[0]+)
/ETHERNET/MDI1_N: J2.R5 (TD2-), U5.9 (MDI[1]-)
/ETHERNET/MDI1_P: J2.R4 (TD2+), U5.8 (MDI[1]+)
/ETHERNET/MDI2_N: J2.R7 (TD3-), U5.12 (MDI[2]-)
/ETHERNET/MDI2_P: J2.R6 (TD3+), U5.11 (MDI[2]+)
/ETHERNET/MDI3_N: J2.R9 (TD4-), U5.15 (MDI[3]-)
/ETHERNET/MDI3_P: J2.R8 (TD4+), U5.14 (MDI[3]+)
/ETHERNET/REG_OUT: L1.1, U5.3 (REG_OUT)
/ETHERNET/RXCLK: U5.24 (RXC); also elsewhere on the board
/ETHERNET/TERM: J2.R10 (GND), R24.1
/ETHERNET/VDD: C15.1, C16.1, L1.2, U5.7 (AVDD10), U5.13 (AVDD10), U5.33 (DVDD10), U5.48 (DVDD10), U5.59 (AVDD10)
/FPGA/ETH_GTXCLK: U5.34 (GTX_CLK); also elsewhere on the board
/FPGA/ETH_MDC: U5.53 (MDC); also elsewhere on the board
/FPGA/ETH_MDIO: R9.2, U5.54 (MDIO); also elsewhere on the board
/FPGA/ETH_RXD0: U5.19 (RXD0); also elsewhere on the board
/FPGA/ETH_RXD1: U5.21 (RXD1); also elsewhere on the board
/FPGA/ETH_RXD2: U5.22 (RXD2); also elsewhere on the board
/FPGA/ETH_RXD3: U5.23 (RXD3); also elsewhere on the board
/FPGA/ETH_RXD4: R10.2, U5.25 (RXD4/SELRGV); also elsewhere on the board
/FPGA/ETH_RXD5: R11.2, U5.27 (RXD5/TXDLY); also elsewhere on the board
/FPGA/ETH_RXD6: R12.2, U5.28 (RXD6/RXDLY); also elsewhere on the board
/FPGA/ETH_RXD7: R13.2, U5.29 (RXD7/AN0); also elsewhere on the board
/FPGA/ETH_RXDV: R17.1, U5.18 (RXDV/PHY_AD2); also elsewhere on the board
/FPGA/ETH_RXER: R15.2, U5.30 (RXER/AN1); also elsewhere on the board
/FPGA/ETH_TXCLK: U5.42 (TXCLK); also elsewhere on the board
/FPGA/ETH_TXD0: U5.36 (TXD0); also elsewhere on the board
/FPGA/ETH_TXD1: U5.39 (TXD1); also elsewhere on the board
/FPGA/ETH_TXD2: U5.40 (TXD2); also elsewhere on the board
/FPGA/ETH_TXD3: U5.41 (TXD3); also elsewhere on the board
/FPGA/ETH_TXD4: U5.43 (TXD4); also elsewhere on the board
/FPGA/ETH_TXD5: U5.44 (TXD5); also elsewhere on the board
/FPGA/ETH_TXD6: U5.45 (TXD6); also elsewhere on the board
/FPGA/ETH_TXD7: U5.46 (TXD7); also elsewhere on the board
/FPGA/ETH_TXEN: U5.35 (TXEN); also elsewhere on the board
/FPGA/ETH_TXER: U5.47 (TXER); also elsewhere on the board
/FPGA/~ETH_PHYRST: R14.1, U5.38 (~PHYRST); also elsewhere on the board
/FPGA/~ETH_PME_INT: U5.55 (~PME), U5.56 (~INT); also elsewhere on the board
GND: C13.2, C14.2, C15.2, C16.2, C17.2, J2.SH, R8.1, R14.2, R16.2, R17.2, R18.2, R20.2, R21.2, R22.2, R23.2, R24.2, U5.2 (GND), U5.4 (GND), U5.63 (GND), U5.65 (EP_GND), X1.2 (GND); also elsewhere on the board
unnamed: D2.1 (K), R18.1
unnamed: D2.2 (A), U5.52 (LED2)
unnamed: R7.2, X1.1 (~ST)
unnamed: R8.2, R19.1
unnamed: R19.2, U5.58 (RSET)

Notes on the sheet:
See datasheet section 9.1 for PSU layout.
50MHz Oscillator LCSC C70528
~PME~ and ~INT~ are combined since the FPGA would handle them in the same way.
Centre tap and ground connection is as per RTL8211C(L) Layout Guide (as found on Baidu). This is the closed document I could find without an NDA. This is Bob Smith termination.
LED circuit is datasheet p.7
Datsheet Table 13 shows some pin strapping options. PHYAD= 000 (use any address) AN= 11 (advertise all capabilities) TXDLY= 1 (add 2ns delay to TXC to allow TXD latching) RXDLY= 1 (add 2ns delay to TXC to allow RXD latching) MODE = 0 (G)MII SELRGV = 1 (3V3 signalling)
ST AN5031 Figure 47 is a useful resource
RSET value is from ST AN5031 Figure 47.

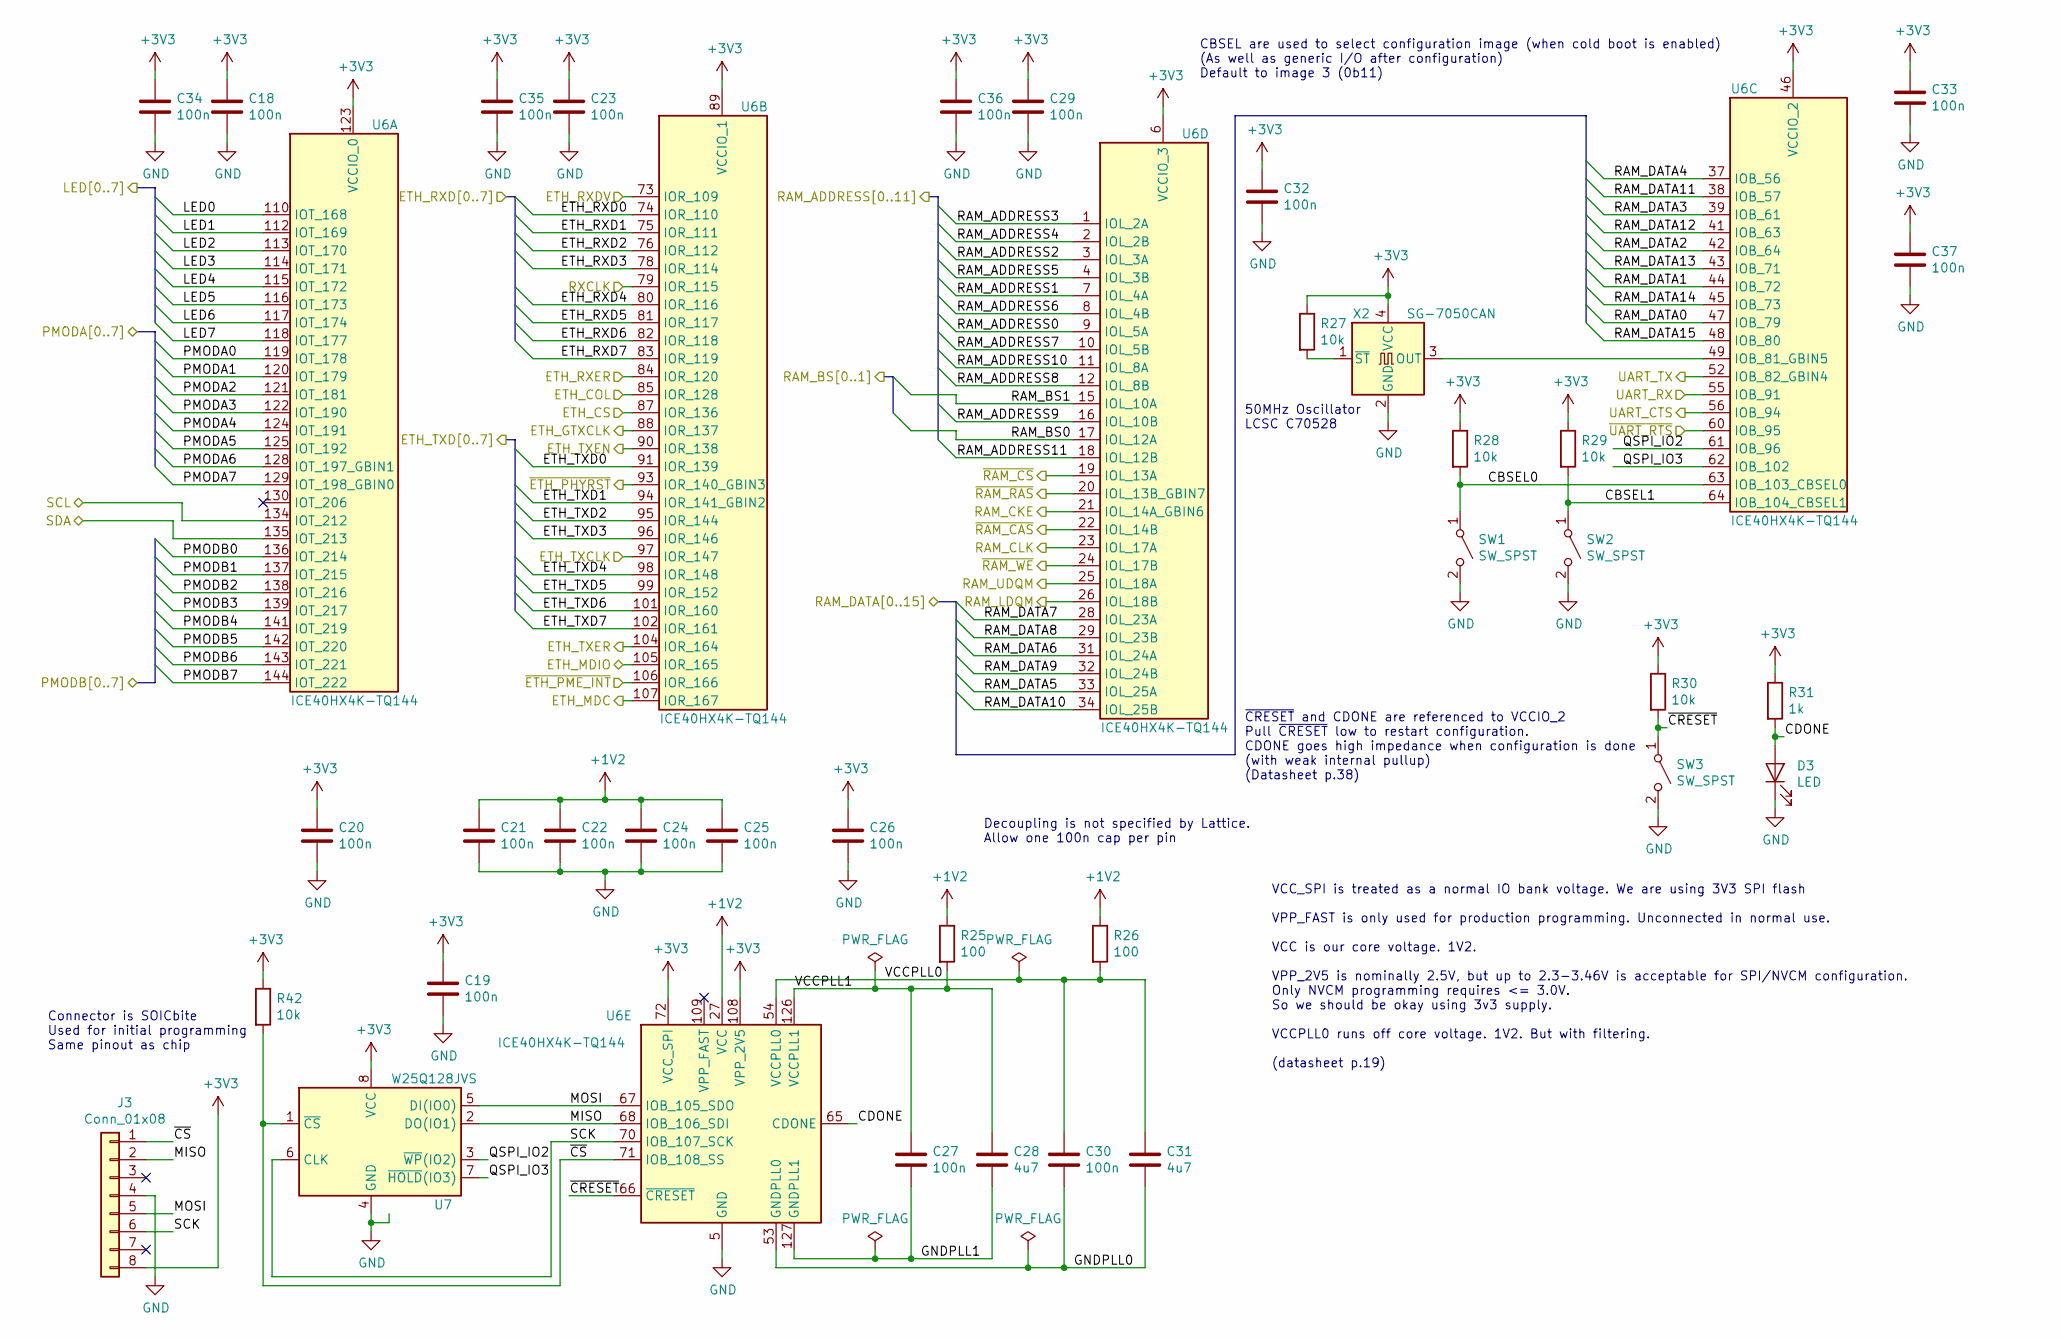
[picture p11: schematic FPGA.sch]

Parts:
C18, C19, C20, C21, C22, C23, C24, C25, C26, C27, C29, C30, C32, C33, C34, C35, C36, C37: 100n; C_0603_1608Metric; LCSC Part C14663
C28, C31: 4u7; C_0603_1608Metric; LCSC Part C19666
D3: LED; D_0805_2012Metric_Castellated; LCSC Part C84256
J3: Conn_01x08; SOIC_clipProgSmall; JLCPCB BOM 0
R25, R26: 100; R_0603_1608Metric; LCSC Part C22775
R27, R28, R29, R30, R42: 10k; R_0603_1608Metric; LCSC Part C25804
R31: 1k; R_0603_1608Metric; LCSC Part C21190
SW1, SW2, SW3: SW_SPST; SW_Push_1P1T_NO_5.1x5.1mm; LCSC Part C318888
U6: ICE40HX4K-TQ144; TQFP-144_20x20mm_P0.5mm; JLCPCB BOM 0
U7: W25Q128JVS; SOIC-8_5.23x5.23mm_P1.27mm; LCSC Part C97521
X2: SG-7050CAN; Oscillator_SMD_SeikoEpson_SG8002CA-4Pin_7.0x5.0mm; LCSC Part C70528

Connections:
+1V2: C21.1, C22.1, C24.1, C25.1, R25.1, R26.1, U6.27 (VCC), U6.40 (VCC), U6.92 (VCC), U6.111 (VCC); also elsewhere on the board
/EEPROM/SCL: U6.134 (IOT_212); also elsewhere on the board
/EEPROM/SDA: U6.135 (IOT_213); also elsewhere on the board
/ETHERNET/COL: U6.85 (IOR_128); also elsewhere on the board
/ETHERNET/CS: U6.87 (IOR_136); also elsewhere on the board
/ETHERNET/RXCLK: U6.79 (IOR_115); also elsewhere on the board
/FPGA/CBSEL0: R28.2, SW1.1 (A), U6.63 (IOB_103_CBSEL0)
/FPGA/CBSEL1: R29.2, SW2.1 (A), U6.64 (IOB_104_CBSEL1)
/FPGA/CDONE: D3.2 (A), R31.2, U6.65 (CDONE)
/FPGA/ETH_GTXCLK: U6.88 (IOR_137); also elsewhere on the board
/FPGA/ETH_MDC: U6.107 (IOR_167); also elsewhere on the board
/FPGA/ETH_MDIO: U6.105 (IOR_165); also elsewhere on the board
/FPGA/ETH_RXD0: U6.74 (IOR_110); also elsewhere on the board
/FPGA/ETH_RXD1: U6.75 (IOR_111); also elsewhere on the board
/FPGA/ETH_RXD2: U6.76 (IOR_112); also elsewhere on the board
/FPGA/ETH_RXD3: U6.78 (IOR_114); also elsewhere on the board
/FPGA/ETH_RXD4: U6.80 (IOR_116); also elsewhere on the board
/FPGA/ETH_RXD5: U6.81 (IOR_117); also elsewhere on the board
/FPGA/ETH_RXD6: U6.82 (IOR_118); also elsewhere on the board
/FPGA/ETH_RXD7: U6.83 (IOR_119); also elsewhere on the board
/FPGA/ETH_RXDV: U6.73 (IOR_109); also elsewhere on the board
/FPGA/ETH_RXER: U6.84 (IOR_120); also elsewhere on the board
/FPGA/ETH_TXCLK: U6.97 (IOR_147); also elsewhere on the board
/FPGA/ETH_TXD0: U6.91 (IOR_139); also elsewhere on the board
/FPGA/ETH_TXD1: U6.94 (IOR_141_GBIN2); also elsewhere on the board
/FPGA/ETH_TXD2: U6.95 (IOR_144); also elsewhere on the board
/FPGA/ETH_TXD3: U6.96 (IOR_146); also elsewhere on the board
/FPGA/ETH_TXD4: U6.98 (IOR_148); also elsewhere on the board
/FPGA/ETH_TXD5: U6.99 (IOR_152); also elsewhere on the board
/FPGA/ETH_TXD6: U6.101 (IOR_160); also elsewhere on the board
/FPGA/ETH_TXD7: U6.102 (IOR_161); also elsewhere on the board
/FPGA/ETH_TXEN: U6.90 (IOR_138); also elsewhere on the board
/FPGA/ETH_TXER: U6.104 (IOR_164); also elsewhere on the board
/FPGA/GNDPLL0: C30.2, C31.2, U6.53 (GNDPLL0)
/FPGA/GNDPLL1: C27.2, C28.2, U6.127 (GNDPLL1)
/FPGA/LED0: U6.110 (IOT_168); also elsewhere on the board
/FPGA/LED1: U6.112 (IOT_169); also elsewhere on the board
/FPGA/LED2: U6.113 (IOT_170); also elsewhere on the board
/FPGA/LED3: U6.114 (IOT_171); also elsewhere on the board
/FPGA/LED4: U6.115 (IOT_172); also elsewhere on the board
/FPGA/LED5: U6.116 (IOT_173); also elsewhere on the board
/FPGA/LED6: U6.117 (IOT_174); also elsewhere on the board
/FPGA/LED7: U6.118 (IOT_177); also elsewhere on the board
/FPGA/MISO: J3.2, U6.68 (IOB_106_SDI), U7.2 (DO(IO1))
/FPGA/MOSI: J3.5, U6.67 (IOB_105_SDO), U7.5 (DI(IO0))
/FPGA/QSPI_IO2: U6.61 (IOB_96), U7.3 (~WP~(IO2))
/FPGA/QSPI_IO3: U6.62 (IOB_102), U7.7 (~HOLD~(IO3))
/FPGA/RAM_UDQM: U6.25 (IOL_18A); also elsewhere on the board
/FPGA/SCK: J3.6, U6.70 (IOB_107_SCK), U7.6 (CLK)
/FPGA/UART_CTS: U6.56 (IOB_94); also elsewhere on the board
/FPGA/UART_RX: U6.55 (IOB_91); also elsewhere on the board
/FPGA/VCCPLL0: C30.1, C31.1, R26.2, U6.54 (VCCPLL0)
/FPGA/VCCPLL1: C27.1, C28.1, R25.2, U6.126 (VCCPLL1)
/FPGA/~CRESET: R30.2, SW3.1 (A), U6.66 (~CRESET)
/FPGA/~CS: J3.1, R42.2, U6.71 (IOB_108_SS), U7.1 (~CS)
/FPGA/~ETH_PHYRST: U6.93 (IOR_140_GBIN3); also elsewhere on the board
/FPGA/~ETH_PME_INT: U6.106 (IOR_166); also elsewhere on the board
/FPGA/~RAM_RAS: U6.20 (IOL_13B_GBIN7); also elsewhere on the board
/FPGA/~RAM_WE: U6.24 (IOL_17B); also elsewhere on the board
/FPGA/~UART_RTS: U6.60 (IOB_95); also elsewhere on the board
/PMODA/DATA0: U6.119 (IOT_178); also elsewhere on the board
/PMODA/DATA1: U6.120 (IOT_179); also elsewhere on the board
/PMODA/DATA2: U6.121 (IOT_181); also elsewhere on the board
/PMODA/DATA3: U6.122 (IOT_190); also elsewhere on the board
/PMODA/DATA4: U6.124 (IOT_191); also elsewhere on the board
/PMODA/DATA5: U6.125 (IOT_192); also elsewhere on the board
/PMODA/DATA6: U6.128 (IOT_197_GBIN1); also elsewhere on the board
/PMODA/DATA7: U6.129 (IOT_198_GBIN0); also elsewhere on the board
/PMODB/DATA0: U6.136 (IOT_214); also elsewhere on the board
/PMODB/DATA1: U6.137 (IOT_215); also elsewhere on the board
/PMODB/DATA2: U6.138 (IOT_216); also elsewhere on the board
/PMODB/DATA3: U6.139 (IOT_217); also elsewhere on the board
/PMODB/DATA4: U6.141 (IOT_219); also elsewhere on the board
/PMODB/DATA5: U6.142 (IOT_220); also elsewhere on the board
/PMODB/DATA6: U6.143 (IOT_221); also elsewhere on the board
/PMODB/DATA7: U6.144 (IOT_222); also elsewhere on the board
/SDRAM/ADDRESS0: U6.9 (IOL_5A); also elsewhere on the board
/SDRAM/ADDRESS1: U6.7 (IOL_4A); also elsewhere on the board
/SDRAM/ADDRESS2: U6.3 (IOL_3A); also elsewhere on the board
/SDRAM/ADDRESS3: U6.1 (IOL_2A); also elsewhere on the board
/SDRAM/ADDRESS4: U6.2 (IOL_2B); also elsewhere on the board
/SDRAM/ADDRESS5: U6.4 (IOL_3B); also elsewhere on the board
/SDRAM/ADDRESS6: U6.8 (IOL_4B); also elsewhere on the board
/SDRAM/ADDRESS7: U6.10 (IOL_5B); also elsewhere on the board
/SDRAM/ADDRESS8: U6.12 (IOL_8B); also elsewhere on the board
/SDRAM/ADDRESS9: U6.16 (IOL_10B); also elsewhere on the board
/SDRAM/ADDRESS10: U6.11 (IOL_8A); also elsewhere on the board
/SDRAM/ADDRESS11: U6.18 (IOL_12B); also elsewhere on the board
/SDRAM/BS0: U6.17 (IOL_12A); also elsewhere on the board
/SDRAM/BS1: U6.15 (IOL_10A); also elsewhere on the board
/SDRAM/CKE: U6.21 (IOL_14A_GBIN6); also elsewhere on the board
/SDRAM/CLK: U6.23 (IOL_17A); also elsewhere on the board
/SDRAM/DATA0: U6.47 (IOB_79); also elsewhere on the board
/SDRAM/DATA1: U6.44 (IOB_72); also elsewhere on the board
/SDRAM/DATA2: U6.42 (IOB_64); also elsewhere on the board
/SDRAM/DATA3: U6.39 (IOB_61); also elsewhere on the board
/SDRAM/DATA4: U6.37 (IOB_56); also elsewhere on the board
/SDRAM/DATA5: U6.33 (IOL_25A); also elsewhere on the board
/SDRAM/DATA6: U6.31 (IOL_24A); also elsewhere on the board
/SDRAM/DATA7: U6.28 (IOL_23A); also elsewhere on the board
/SDRAM/DATA8: U6.29 (IOL_23B); also elsewhere on the board
/SDRAM/DATA9: U6.32 (IOL_24B); also elsewhere on the board
/SDRAM/DATA10: U6.34 (IOL_25B); also elsewhere on the board
/SDRAM/DATA11: U6.38 (IOB_57); also elsewhere on the board
/SDRAM/DATA12: U6.41 (IOB_63); also elsewhere on the board
/SDRAM/DATA13: U6.43 (IOB_71); also elsewhere on the board
/SDRAM/DATA14: U6.45 (IOB_73); also elsewhere on the board
/SDRAM/DATA15: U6.48 (IOB_80); also elsewhere on the board
/SDRAM/LDQM: U6.26 (IOL_18B); also elsewhere on the board
/SDRAM/~CAS: U6.22 (IOL_14B); also elsewhere on the board
/SDRAM/~CS: U6.19 (IOL_13A); also elsewhere on the board
/USB_UART/UART_RX: U6.52 (IOB_82_GBIN4); also elsewhere on the board
GND: C18.2, C19.2, C20.2, C21.2, C22.2, C23.2, C24.2, C25.2, C26.2, C29.2, C32.2, C33.2, C34.2, C35.2, C36.2, C37.2, D3.1 (K), J3.4, SW1.2 (B), SW2.2 (B), SW3.2 (B), U6.5 (GND), U6.13 (GND), U6.14 (GND), U6.59 (GND), U6.69 (GND), U6.86 (GND), U6.103 (GND), U6.132 (GND), U6.140 (GND), U7.4 (GND), X2.2 (GND); also elsewhere on the board
unnamed: R27.2, X2.1 (~ST)
unnamed: U6.49 (IOB_81_GBIN5), X2.3 (OUT)

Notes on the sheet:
VCC_SPI is treated as a normal IO bank voltage. We are using 3V3 SPI flash VPP_FAST is only used for production programming. Unconnected in normal use. VCC is our core voltage. 1V2. VPP_2V5 is nominally 2.5V, but up to 2.3-3.46V is acceptable for SPI/NVCM configuration. Only NVCM programming requir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
Decoupling is not specified by Lattice. Allow one 100n cap per pin
Connector is SOICbite Used for initial programming Same pinout as chip
~CRESET~ and CDONE are referenced to VCCIO_2 Pull ~CRESET~ low to restart configuration. CDONE goes high impedance when configuration is done (with weak internal pullup) (Datasheet p.38)
CBSEL are used to select configuration image (when cold boot is enabled) (As well as generic I/O after configuration) Default to image 3 (0b11)
50MHz Oscillator LCSC C70528

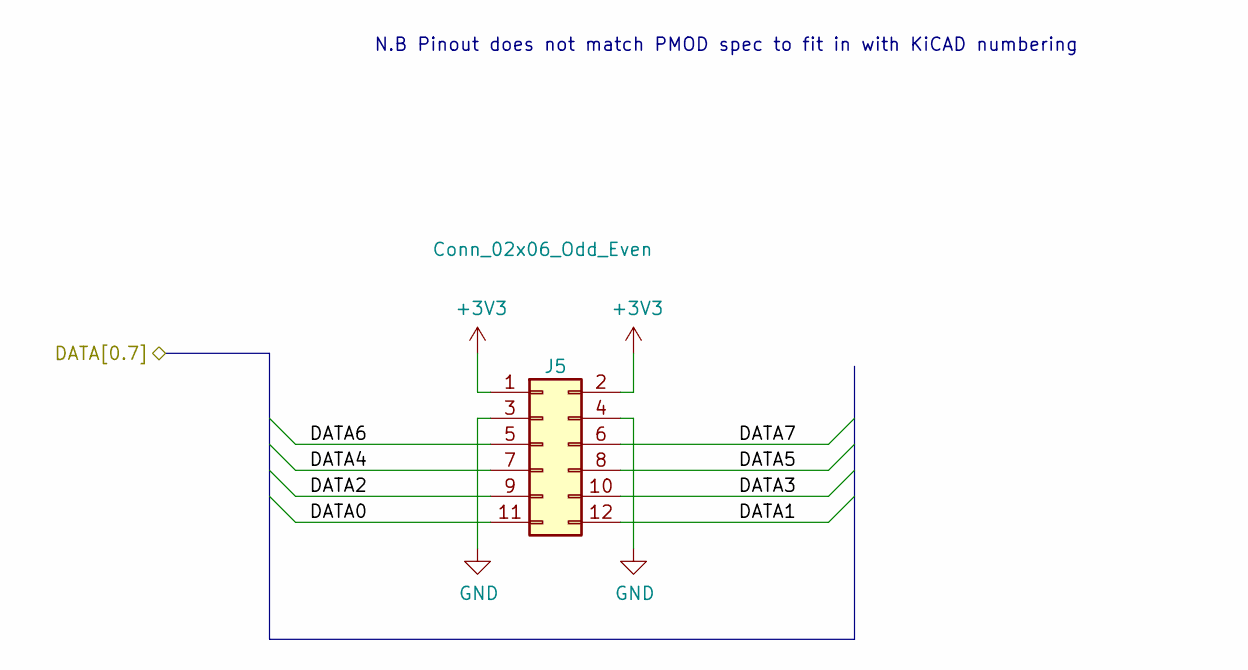
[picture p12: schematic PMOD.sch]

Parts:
J4: Conn_02x06_Odd_Even; PinSocket_2x06_P2.54mm_Horizontal; JLCPCB BOM 0

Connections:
/PMODA/DATA0: J4.11; also elsewhere on the board
/PMODA/DATA1: J4.12; also elsewhere on the board
/PMODA/DATA2: J4.9; also elsewhere on the board
/PMODA/DATA3: J4.10; also elsewhere on the board
/PMODA/DATA4: J4.7; also elsewhere on the board
/PMODA/DATA5: J4.8; also elsewhere on the board
/PMODA/DATA6: J4.5; also elsewhere on the board
/PMODA/DATA7: J4.6; also elsewhere on the board
GND: J4.3, J4.4; also elsewhere on the board

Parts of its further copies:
J5: Conn_02x06_Odd_Even; PinSocket_2x06_P2.54mm_Horizontal; JLCPCB BOM 0

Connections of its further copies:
/PMODB/DATA0: J5.11; also elsewhere on the board
/PMODB/DATA1: J5.12; also elsewhere on the board
/PMODB/DATA2: J5.9; also elsewhere on the board
/PMODB/DATA3: J5.10; also elsewhere on the board
/PMODB/DATA4: J5.7; also elsewhere on the board
/PMODB/DATA5: J5.8; also elsewhere on the board
/PMODB/DATA6: J5.5; also elsewhere on the board
/PMODB/DATA7: J5.6; also elsewhere on the board
GND: J5.3, J5.4; also elsewhere on the board

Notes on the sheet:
N.B Pinout does not match PMOD spec to fit in with KiCAD numbering

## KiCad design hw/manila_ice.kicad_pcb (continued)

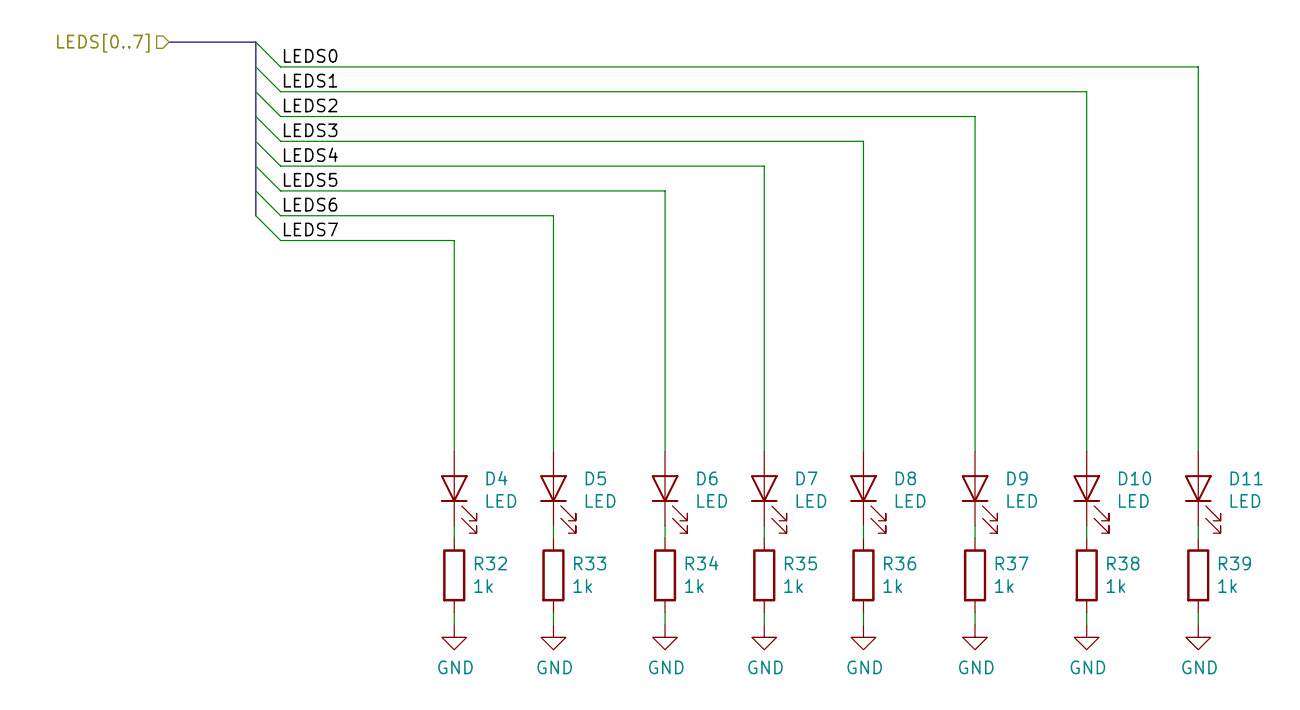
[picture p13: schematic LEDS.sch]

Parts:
D4, D5, D6, D7, D8, D9, D10, D11: LED; D_0805_2012Metric_Castellated; LCSC Part C84256
R32, R33, R34, R35, R36, R37, R38, R39: 1k; R_0603_1608Metric; LCSC Part C21190

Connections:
/FPGA/LED0: D11.2 (A); also elsewhere on the board
/FPGA/LED1: D10.2 (A); also elsewhere on the board
/FPGA/LED2: D9.2 (A); also elsewhere on the board
/FPGA/LED3: D8.2 (A); also elsewhere on the board
/FPGA/LED4: D7.2 (A); also elsewhere on the board
/FPGA/LED5: D6.2 (A); also elsewhere on the board
/FPGA/LED6: D5.2 (A); also elsewhere on the board
/FPGA/LED7: D4.2 (A); also elsewhere on the board
GND: R32.2, R33.2, R34.2, R35.2, R36.2, R37.2, R38.2, R39.2; also elsewhere on the board
unnamed: D4.1 (K), R32.1
unnamed: D5.1 (K), R33.1
unnamed: D6.1 (K), R34.1
unnamed: D7.1 (K), R35.1
unnamed: D8.1 (K), R36.1
unnamed: D9.1 (K), R37.1
unnamed: D10.1 (K), R38.1
unnamed: D11.1 (K), R39.1

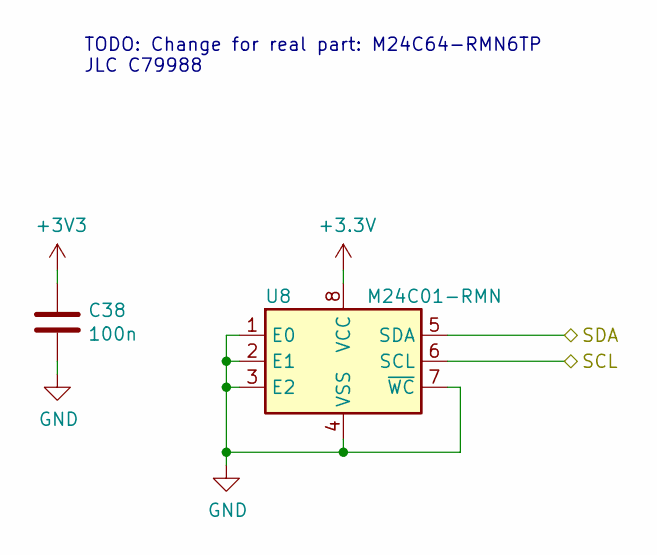
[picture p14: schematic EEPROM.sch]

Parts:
C38: 100n; C_0603_1608Metric; LCSC Part C14663
U8: M24C01-RMN; SOIC-8_3.9x4.9mm_P1.27mm; LCSC Part C79988

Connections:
/EEPROM/SCL: U8.6 (SCL); also elsewhere on the board
/EEPROM/SDA: U8.5 (SDA); also elsewhere on the board
GND: C38.2, U8.1 (E0), U8.2 (E1), U8.3 (E2), U8.4 (VSS), U8.7 (~WC); also elsewhere on the board

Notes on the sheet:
TODO: Change for real part: M24C64-RMN6TP JLC C79988

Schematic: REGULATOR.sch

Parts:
C10, C42, C43, C44: 22u; C_0603_1608Metric; LCSC Part C59461
C11, C41: 100n; C_0603_1608Metric; LCSC Part C14663
C12: 10p; C_0603_1608Metric; LCSC Part C1634
C39: 1n; C_0603_1608Metric; LCSC Part C1588
C40: 10n; C_0603_1608Metric; LCSC Part C57112
C45: 100u; CP_EIA-3528-21_Kemet-B; LCSC Part C16133
D12: SS54; D_SMA; LCSC Part C22452
L2: 2u2; L_Sunlord_MWSA0518; LCSC Part C408345
R43: 43k; R_0603_1608Metric; LCSC Part C23172
U3: TPS54331D; SOIC-8_3.9x4.9mm_P1.27mm; LCSC Part C9865

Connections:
+1V2: C42.1, C43.1, C44.1, C45.1, L2.2; also elsewhere on the board
/1V2_REG/BOOT: C41.1, U3.1 (BOOT)
/1V2_REG/COMP: C12.1, R43.1, U3.6 (COMP)
/1V2_REG/COMP_RC: C39.1, R43.2
/1V2_REG/FB: U3.5 (FB); also elsewhere on the board
/1V2_REG/PH: C41.2, D12.1 (K), L2.1, U3.8 (PH)
/1V2_REG/SS: C40.1, U3.4 (SS)
/5V: C10.1, C11.1, U3.2 (VIN); also elsewhere on the board
GND: C10.2, C11.2, C12.2, C39.2, C40.2, C42.2, C43.2, C44.2, C45.2, D12.2 (A), U3.7 (GND); also elsewhere on the board

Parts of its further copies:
C46, C52, C53, C54: 22u; C_0603_1608Metric; LCSC Part C59461
C47, C51: 100n; C_0603_1608Metric; LCSC Part C14663
C48: 10p; C_0603_1608Metric; LCSC Part C1634
C49: 1n; C_0603_1608Metric; LCSC Part C1588
C50: 10n; C_0603_1608Metric; LCSC Part C57112
C55: 100u; CP_EIA-3528-21_Kemet-B; LCSC Part C16133
D13: SS54; D_SMA; LCSC Part C22452
L3: 2u2; L_Sunlord_MWSA0518; LCSC Part C408345
R44: 43k; R_0603_1608Metric; LCSC Part C23172
U4: TPS54331D; SOIC-8_3.9x4.9mm_P1.27mm; LCSC Part C9865

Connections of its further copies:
/3V3_REG/BOOT: C51.1, U4.1 (BOOT)
/3V3_REG/COMP: C48.1, R44.1, U4.6 (COMP)
/3V3_REG/COMP_RC: C49.1, R44.2
/3V3_REG/FB: U4.5 (FB); also elsewhere on the board
/3V3_REG/PH: C51.2, D13.1 (K), L3.1, U4.8 (PH)
/3V3_REG/SS: C50.1, U4.4 (SS)
/5V: C46.1, C47.1, U4.2 (VIN); also elsewhere on the board
GND: C46.2, C47.2, C48.2, C49.2, C50.2, C52.2, C53.2, C54.2, C55.2, D13.2 (A), U4.7 (GND); also elsewhere on the board

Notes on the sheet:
3A max output. Designed using TI webench (tweaked from default values) Inductor value is a little low, but allows part reuse
Vref = 0.8V

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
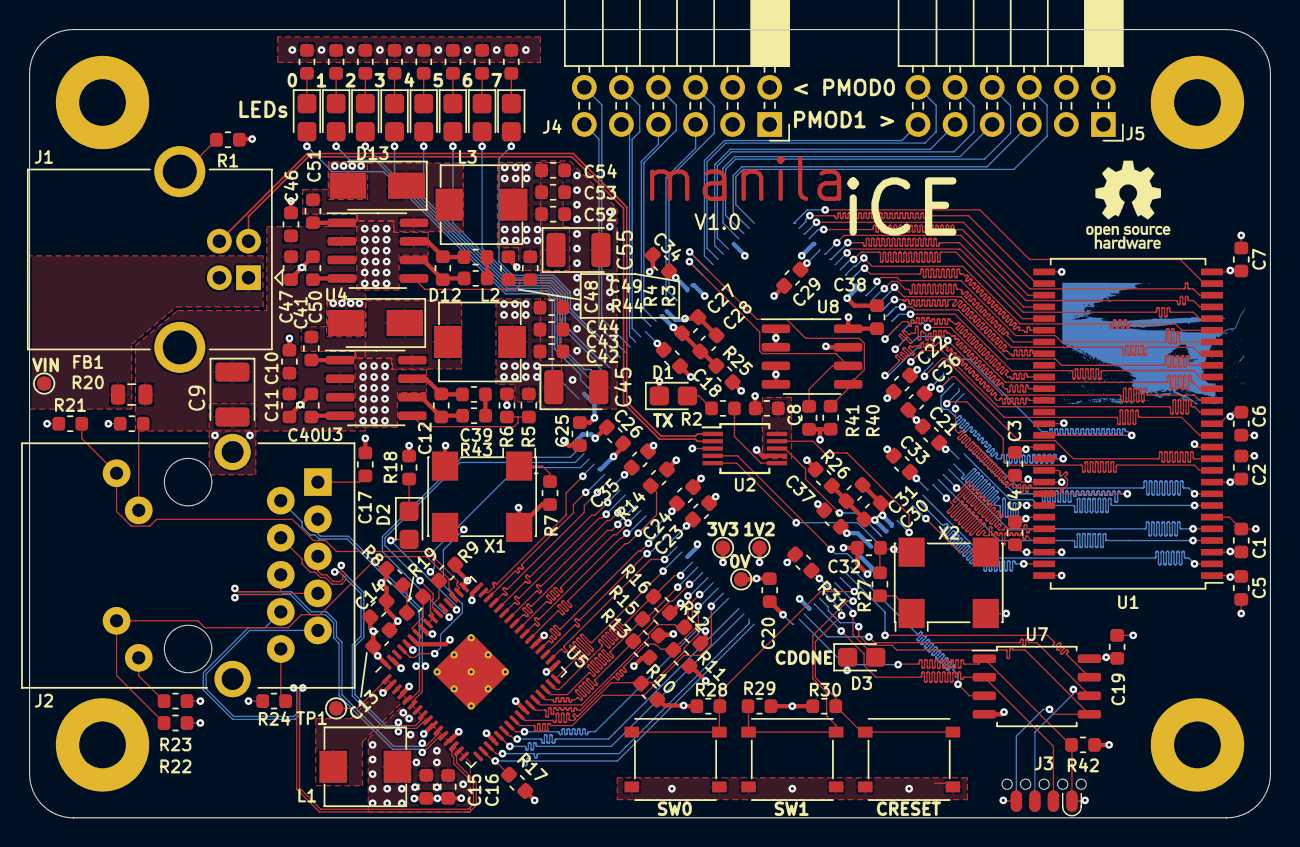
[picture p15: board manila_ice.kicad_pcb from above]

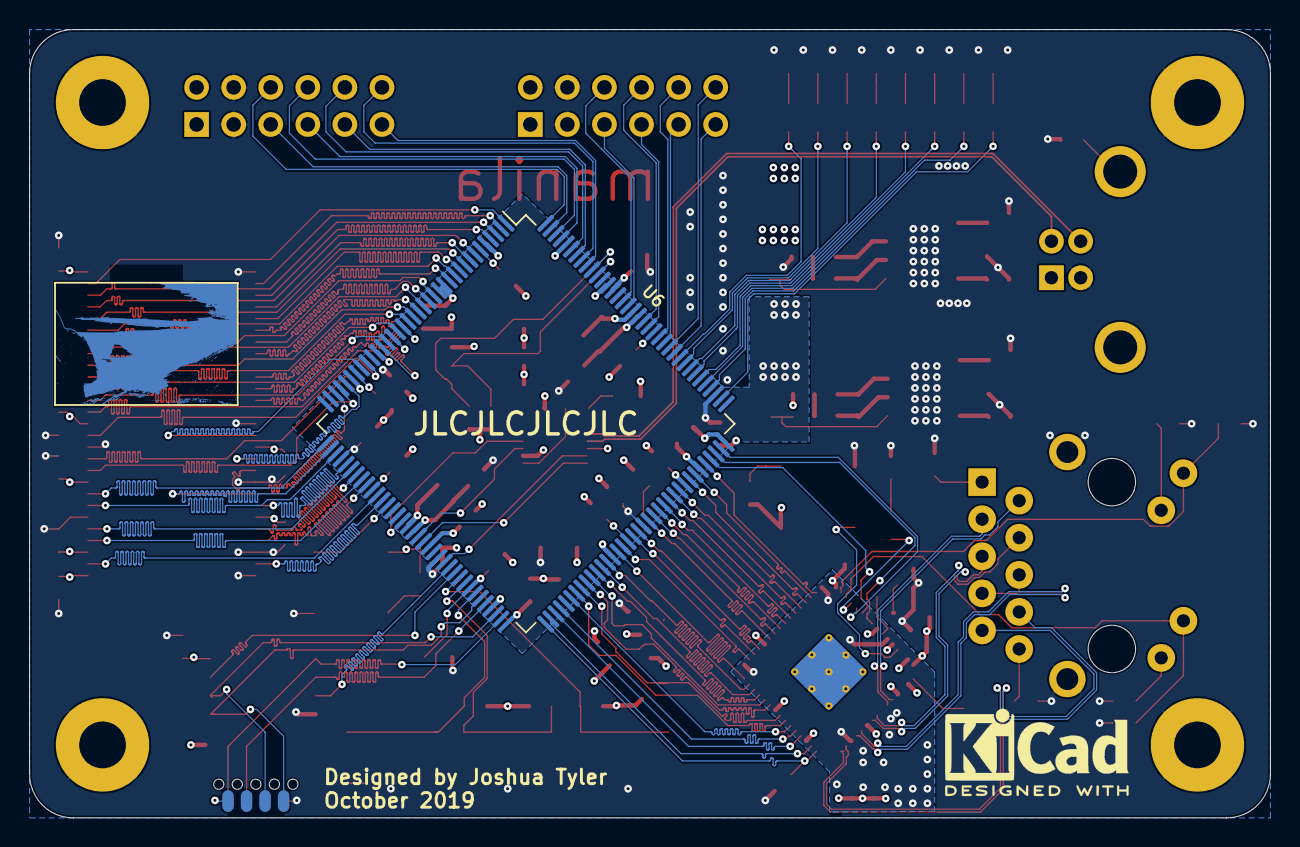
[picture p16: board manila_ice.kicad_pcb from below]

Board: 4 copper layers, 85.0 x 54.0 mm, 146 parts (3 on the bottom side), 166 nets.

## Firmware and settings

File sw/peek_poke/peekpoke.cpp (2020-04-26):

#include <iostream>
#include <vector>
#include "VectorUtility.h"
#include "WbUart.hpp"

int main(int argc, char** argv)
{
	if(argc < 5)
	{

		std::cerr << "Usage: " << argv[0] << " [uart] [baud] [r/w] [address] [data if w]" << std::endl;
		return 0;
	}
	WbUart<uint8_t,8> uart(argv[1], std::atoi(argv[2]), true);
	if(argv[3][0] == 'w')
	{
		std::vector<uint8_t> vec = {std::atoi(argv[5])};
		uart.write(std::atoi(argv[4]), AddressMode::INCREMENT, vec.begin(), vec.end());
	} else {
		VectorUtility::print(uart.read(std::atoi(argv[4]), AddressMode::INCREMENT, 1));
	}

	return 0;
}

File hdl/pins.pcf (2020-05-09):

# manila iCE constraints

set_io clk 49

set_io leds[0] 110
set_io leds[1] 112
set_io leds[2] 113
set_io leds[3] 114
set_io leds[4] 115
set_io leds[5] 116
set_io leds[6] 117
set_io leds[7] 118

set_io buttons[0] 63
set_io buttons[1] 64

set_io pmod0[0] 119
set_io pmod0[1] 120
set_io pmod0[2] 121
set_io pmod0[3] 122
set_io pmod0[4] 124
set_io pmod0[5] 125
set_io pmod0[6] 128
set_io pmod0[7] 129

set_io pmod1[0] 136
set_io pmod1[1] 137
set_io pmod1[2] 138
set_io pmod1[3] 139
set_io pmod1[4] 141
set_io pmod1[5] 142
set_io pmod1[6] 143
set_io pmod1[7] 144

set_io uart_tx    52
set_io uart_rx    55
set_io uart_cts_n 56
set_io uart_rts_n 60

set_io spi_mosi   67
set_io spi_miso   68
set_io spi_sck    70
set_io spi_ss     71
set_io spi_wp_n   61
set_io spi_hold_n 62

set_io i2c_scl  130
set_io i2c_wc_n 134
set_io i2c_sda  135

set_io eth_phyrst_n  93
set_io eth_rxdv      73
set_io eth_gtxclk    88
set_io eth_txen      90
set_io eth_txer      104
set_io eth_rxclk     79
set_io eth_rxer      84
set_io eth_col       85
set_io eth_cs        87
set_io eth_txclk     97
set_io eth_mdio      105
set_io eth_mdc       107
set_io eth_pme_int_n 106
set_io eth_rxd[0]    74
set_io eth_rxd[1]    75
set_io eth_rxd[2]    76
set_io eth_rxd[3]    78
set_io eth_rxd[4]    80
set_io eth_rxd[5]    81
set_io eth_rxd[6]    82
set_io eth_rxd[7]    83
set_io eth_txd[0]    91
set_io eth_txd[1]    94
set_io eth_txd[2]    95
set_io eth_txd[3]    96
set_io eth_txd[4]    98
set_io eth_txd[5]    99
set_io eth_txd[6]    101
set_io eth_txd[7]    102

set_io sdram_clk      23
set_io sdram_cke      21
set_io sdram_cs_n     19
set_io sdram_ras_n    20
set_io sdram_cas_n    22
set_io sdram_we_n     24
set_io sdram_bs[0]    17
set_io sdram_bs[1]    15
set_io sdram_addr[0]  9
set_io sdram_addr[1]  7
set_io sdram_addr[2]  3
set_io sdram_addr[3]  1
set_io sdram_addr[4]  2
set_io sdram_addr[5]  4
set_io sdram_addr[6]  8
set_io sdram_addr[7]  10
set_io sdram_addr[8]  12
set_io sdram_addr[9]  16
set_io sdram_addr[10] 11
set_io sdram_addr[11] 18
set_io sdram_data[0]  47
set_io sdram_data[1]  44
set_io sdram_data[2]  42
set_io sdram_data[3]  39
set_io sdram_data[4]  37
set_io sdram_data[5]  33
set_io sdram_data[6]  31
set_io sdram_data[7]  28
set_io sdram_data[8]  29
set_io sdram_data[9]  32
set_io sdram_data[10] 34
set_io sdram_data[11] 38
set_io sdram_data[12] 41
set_io sdram_data[13] 43
set_io sdram_data[14] 45
set_io sdram_data[15] 48
set_io sdram_dqm[0]   26
set_io sdram_dqm[1]   25

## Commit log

2019-09-29 First complete commit
    [ETHERNET.sch, FPGA.sch, LEDS.sch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]
2019-10-07 Commit before messing with via sizes for JLC compliance
    [ETHERNET.sch, FPGA.sch, LEDS.sch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]
2019-10-07 Pre tuning of DDR length matching
    [FPGA.sch, hx4k_dev_board.kicad_pcb]
2019-10-08 Fully routed
    [ETHERNET.sch, FPGA.sch, POWER.sch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]
2019-10-13 PMODs corrected
    [PMOD.sch, hx4k_dev_board.kicad_pcb]
2019-10-15 Basically done.
    [PMOD.sch, hx4k_dev_board.kicad_pcb, hx4k_dev_board.sch]
2019-10-17 Add EEPROM
    [EEPROM.sch, ETHERNET.sch, FPGA.sch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]
2019-10-19 Tidy up
    [hx4k_dev_board.kicad_pcb]
2019-10-19 Change folder structure
    [EEPROM.sch, ETHERNET.sch, FPGA.sch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]
2019-10-19 Add kicad-footprints and kicad-symbols used for this project as submodules.
    This is done because not all prs have been merged into kicad master yet.
2019-10-19 Add outputs folder
    [EEPROM.sch, ETHERNET.sch, FPGA.sch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]
2019-10-19 Rename project
    [manila_ice.kicad_pcb, manila_ice.sch]
2019-10-19 Add forgotten pullup to SPI flash ~CS
    [EEPROM.sch, ETHERNET.sch, FPGA.sch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]
2019-10-19 Add comment
    [POWER.sch]
2019-10-19 Add fab outputs
    [manila_ice-B_Cu.gbr, manila_ice-B_Mask.gbr, manila_ice-B_Paste.gbr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]
2019-10-19 Finished except some parts need to be rotated
    [manila_ice-B_Cu.gbr, manila_ice-B_Mask.gbr, manila_ice-B_Paste.gbr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]
2019-10-21 Add ability to rotate part for JLC PCB
    [USB_UART.sch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]
2019-10-21 Replace ethernet SMPS inductor with a sensible power rating
    [ETHERNET.sch]
2019-10-22 Added ground pour on bottom. Fixed DRC errors
2019-10-23 Move to switched mode regulators. Layout not complete yet
    [EEPROM.sch, ETHERNET.sch, FPGA.sch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]
2019-10-23 Plumbed in SMPS
    [ETHERNET.sch, FPGA.sch, LEDS.sch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]
2019-10-24 Resize refdes
    [manila_ice.kicad_pcb]
2019-10-24 Minor tweak to font size
    [manila_ice.kicad_pcb]
2019-10-27 Fixed tant footprint. Added JLC part numbers to other components
    [EEPROM.sch, ETHERNET.sch, FPGA.sch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]
2019-10-27 Add ESD protection
    [EEPROM.sch, ETHERNET.sch, FPGA.sch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]
2019-10-28 Fix JLC rotation
    [EEPROM.sch, ETHERNET.sch, FPGA.sch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]
2019-10-31 Changed stackup to JLC7628
    [manila_ice-B_Cu.gbr, manila_ice-B_Mask.gbr, manila_ice-B_Paste.gbr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]
2019-11-02 Remove all thin traces from power nets
2019-11-02 Update schematic to change slew rates of PSUs and to add switch debouncing
    [EEPROM.sch, ETHERNET.sch, FPGA.sch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]
2019-11-02 Schematic tweaks
    [EEPROM.sch, ETHERNET.sch, FPGA.sch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]
2019-11-03 Ready for fab
    [manila_ice-B_Cu.gbr, manila_ice-B_Mask.gbr, manila_ice-B_Paste.gbr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]
2019-11-11 Add working UART
2020-01-02 Remove accidentally committed file
    [costs.ods]
2020-01-04 Basic UART working
2020-02-02 Fixup makefiles. Stop recording VCD for speed
    [test_loopback_test.cpp]
2020-02-13 Steps towards bootstrap support in hx4k dev board
2020-02-25 Reading device ID in sim
2020-03-03 Able to program flash fairly quickly. Not working at 2M baud for an unknown reason
    [pins.pcf, test_bootstrap.cpp]
2020-03-05 Add experimental flow control support
2020-03-08 Add spi data injection/extraction. Not currently working in hardware
2020-03-08 Correct pinout for UART flow control
    [pins.pcf]
2020-03-08 Add spi_prog as a submodule, so we can track development with the hdl
2020-04-11 Playing back SPI commands at boot working
2020-04-26 Bootstrap working with buttons to select image
2020-04-26 Add script to find the serial device a manila ice is connected to
2020-05-09 Increase timeout and recognise when the board has output nothing
2020-05-09 Remove kicad footprints and kicad symbols submodules
    These symbols are all cached in the schematic, and will be upstream eventually anyway
2020-05-26 Basic picorv32 working (although only in default SPI mode at the moment)
